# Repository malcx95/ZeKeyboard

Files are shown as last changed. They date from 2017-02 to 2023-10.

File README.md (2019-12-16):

# ZeKeyboard

ZeKeyboard is a series of home-made RGB-backlit mechanical keyboards, 
with 3D-printed bodies and custom firmware. 3 keyboards have been made,
one with 60% layout, one with a full size layout, and most recently one
with a 60% layout plus a numpad (the "V2" keyboard). This repository contains all the source
code for the firmware, as well as the 3D-models of the keyboards.

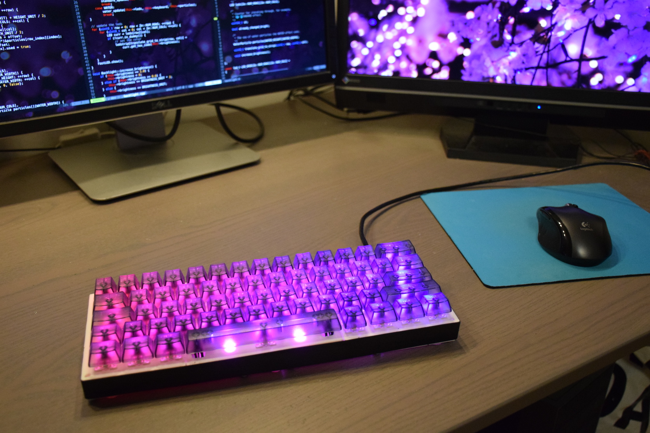
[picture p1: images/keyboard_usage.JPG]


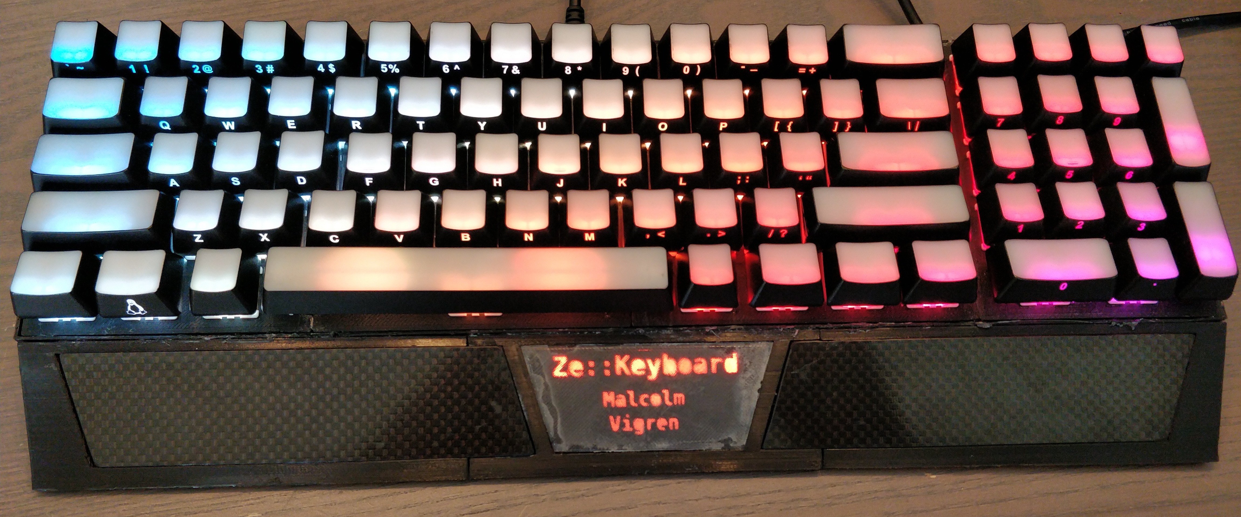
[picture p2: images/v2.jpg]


## Layout and body

The first keyboard was the one with the 60% layout, pictured below. It uses the ANSI-style Enter-key,
as well as the ISO-style left-shift key.

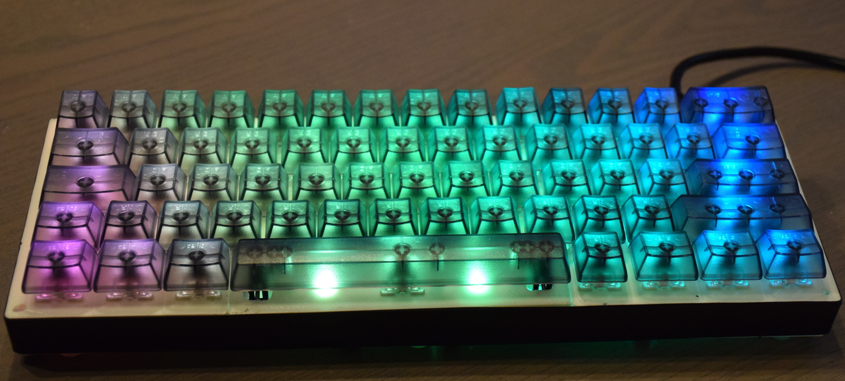
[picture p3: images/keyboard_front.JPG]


The layout for this keyboard was partially generated using scripts and 
template OpenSCAD-files by [TheZoq2](https://github.com/TheZoq2/), which
you can find [here](https://github.com/TheZoq2/Keyboard). These OpenSCAD-files
contained the switch holes corresponding to the json-layout generated from 
[here](http://www.keyboard-layout-editor.com/), and were modeled further
in Blender to form a keyboard body.

The layout for the fullsize keyboard (picture unavailable) and the V2 keyboard (pictured below)
could not be generated using the aforementioned script, so they were manually modeled
in Blender from the json-layout generated from [here](http://www.keyboard-layout-editor.com/).
The V2 body also features carbon fibre handrests.

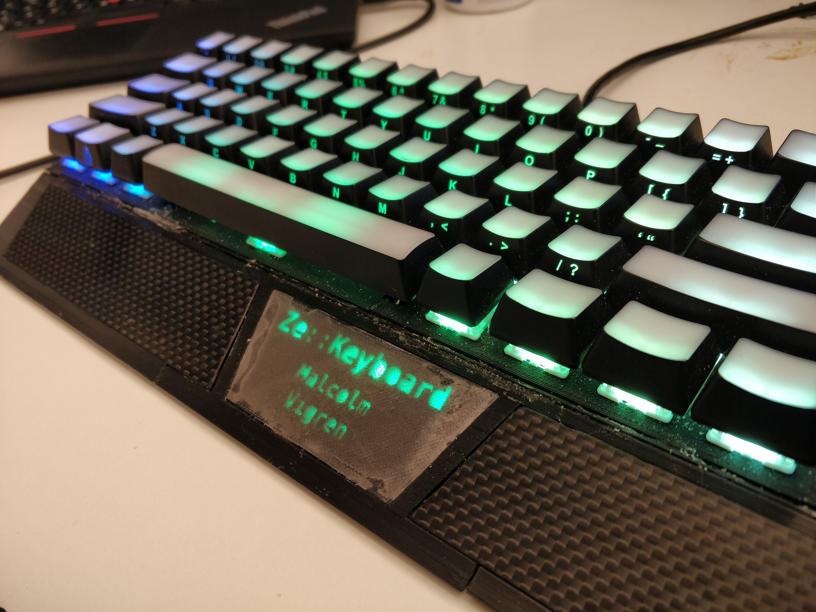
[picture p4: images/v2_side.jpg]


## Switches

All keyboards use Gateron Brown mechanical switches, which are very similar to 
Cherry MX Brown, in the sense that they have tactile feedback without a click. These
particular switches are the SMD-LED-compatible ones, meaning they have a white body
with clear top, and a large hole for an SMD-LED to shine through.

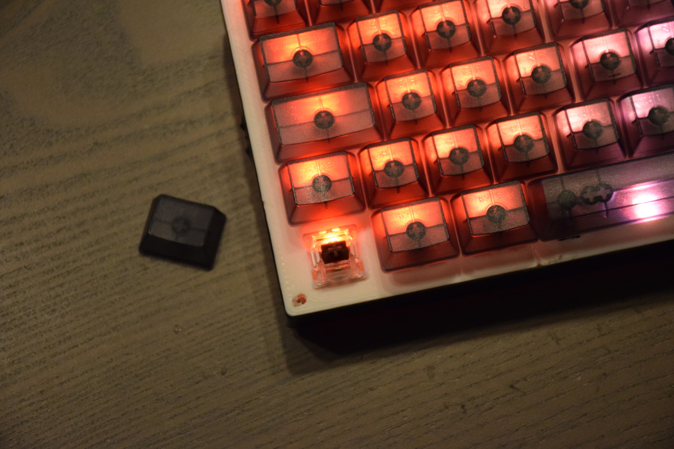
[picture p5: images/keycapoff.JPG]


## Backlight

The backlight consists of Adafruit Neopixel RGB-LEDs. Each LED is hot-glued in place
right below each switch to shine through the 
hole in the switch, lighting up the keycap. This lights
each keycap up more uniformly than LED:s mounted right below the keycap.
On the 60% and V2 keyboard are also two extra LED:s for the spacebar, to the left and right of the main LED.

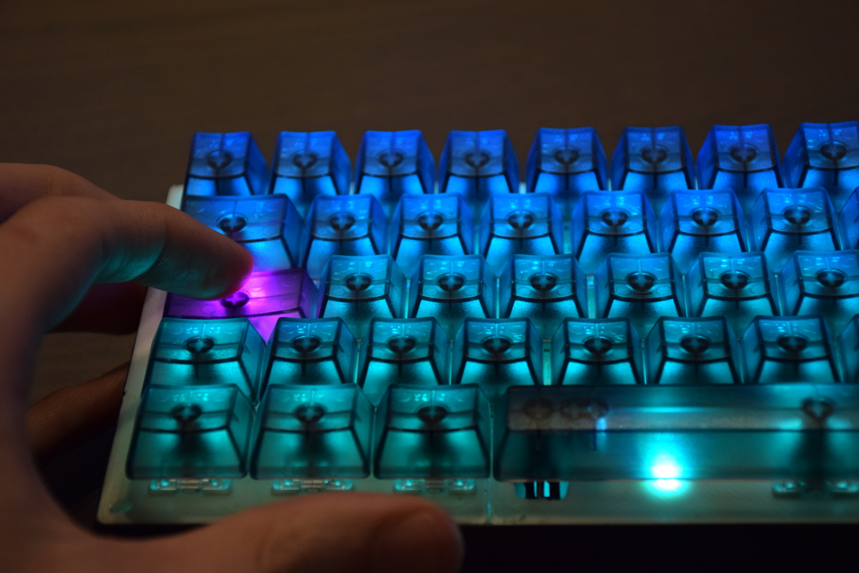
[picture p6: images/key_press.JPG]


On the V2 keyboard, there are three LED:s shining inside a cavity in the handrest, illuminating
the ZeKeyboard logo.



## Controller

For the 60% keyboard, the controller used is a Teensy 3.2. I could have chosen a cheaper Teensy, like
Teensy LC, but I wanted enough computing power for the effects I was going to implement.
Also, at the time of purchase, I had a different approach to implementing the 
backlight (involving five TLC5940 chips), which required the extra ports available on the
more expensive Teensy 3.2.

For the other keyboards, due to the larger number of keys, a Teensy 3.5 is used, as it's faster
and has more RAM.

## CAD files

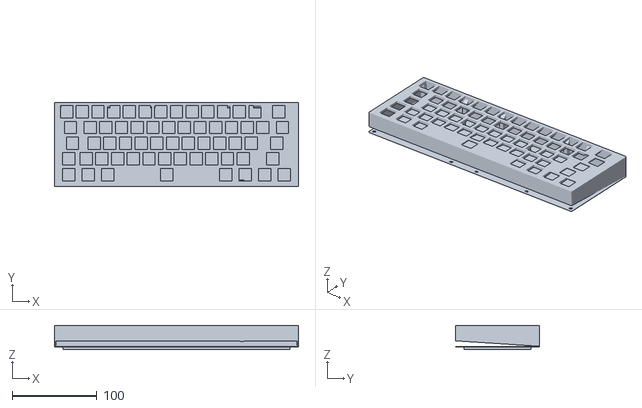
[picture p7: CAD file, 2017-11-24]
design/keyboard.stl
287.5 x 99.5 x 28.7

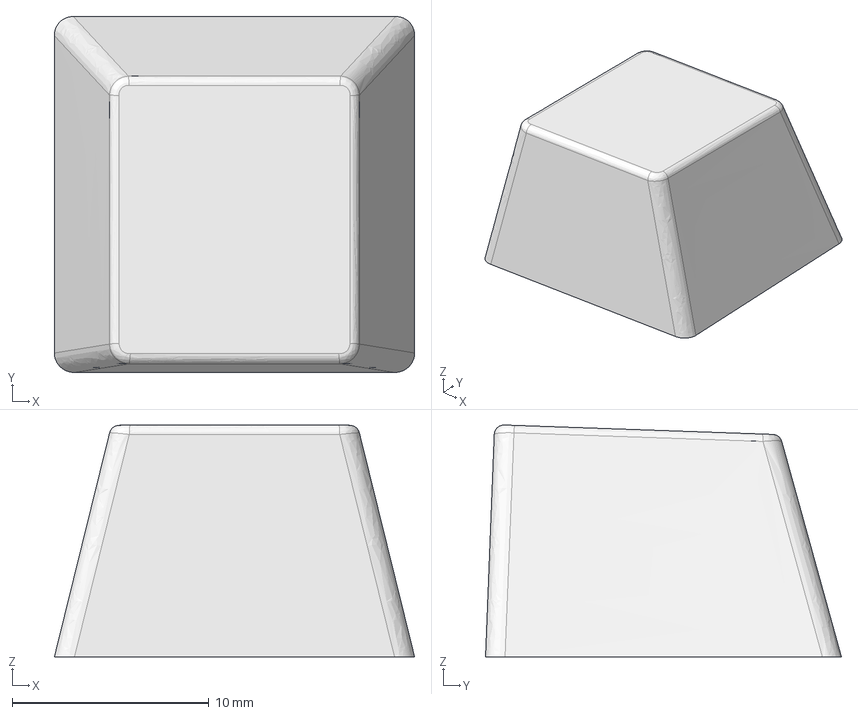
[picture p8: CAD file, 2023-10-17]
v3/case/keycap.FCStd
18.3 x 18.1 x 11.8 mm

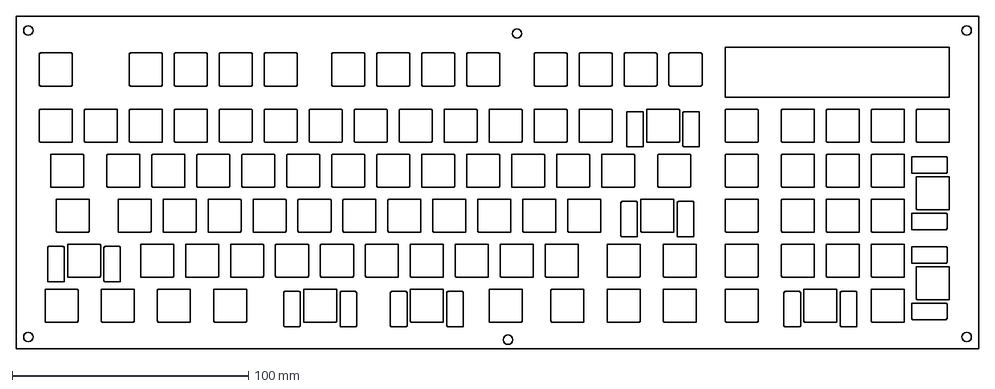
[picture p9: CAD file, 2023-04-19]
v3/pcb/production/plate/inner_plate.dxf
407.7 x 140.9 mm

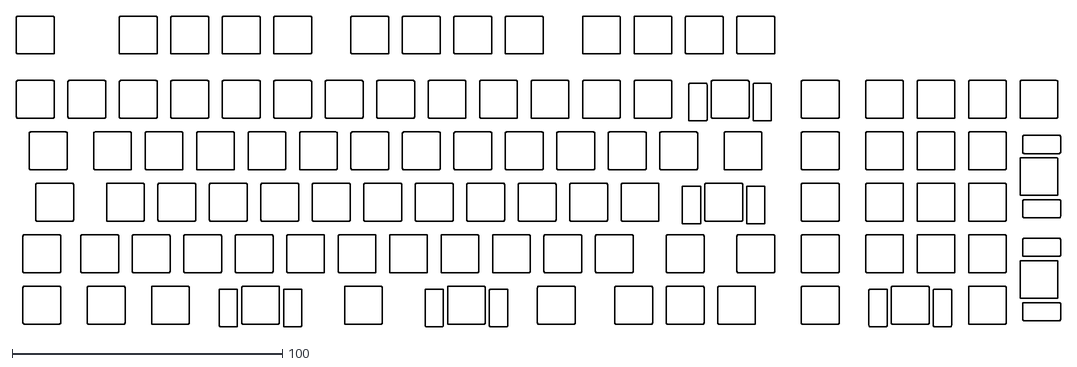
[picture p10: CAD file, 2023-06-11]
v3/case/v3-User_Eco2.dxf
386.5 x 115.0

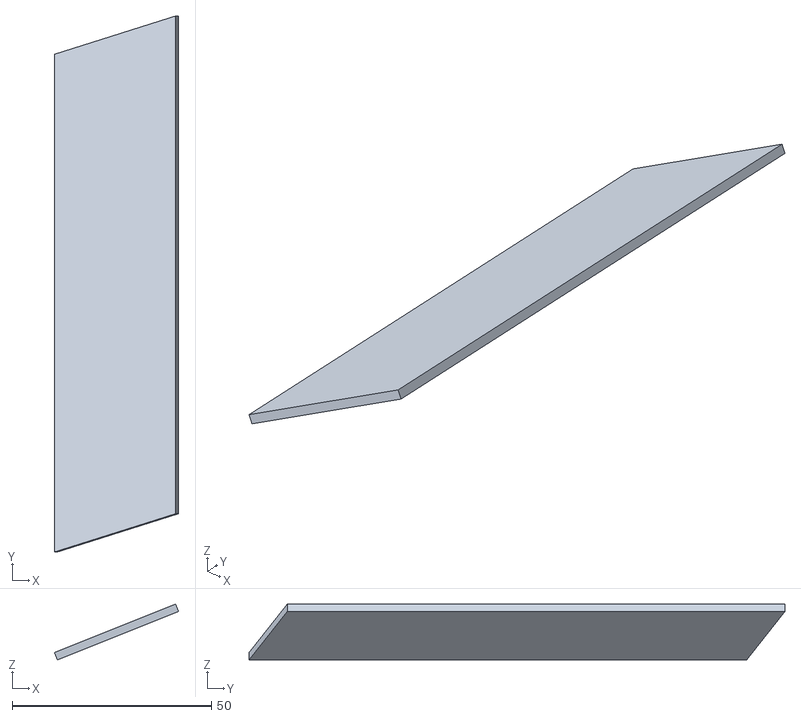
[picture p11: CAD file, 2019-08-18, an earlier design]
v2/cffull.stl
31.2 x 134.6 x 14.0

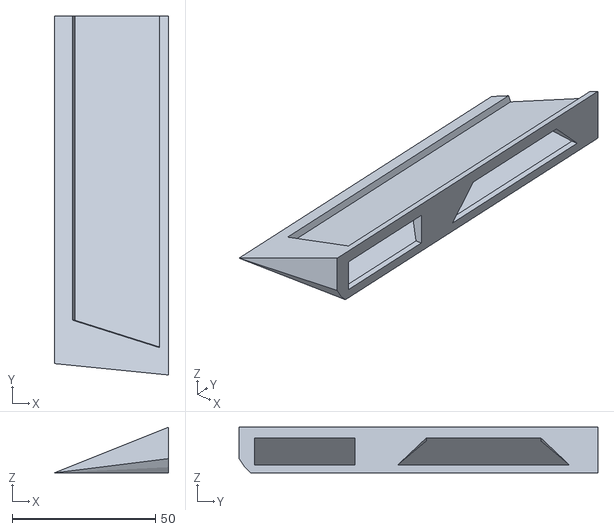
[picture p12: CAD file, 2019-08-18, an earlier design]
v2/handrest_right_full.stl
40.0 x 125.5 x 16.0

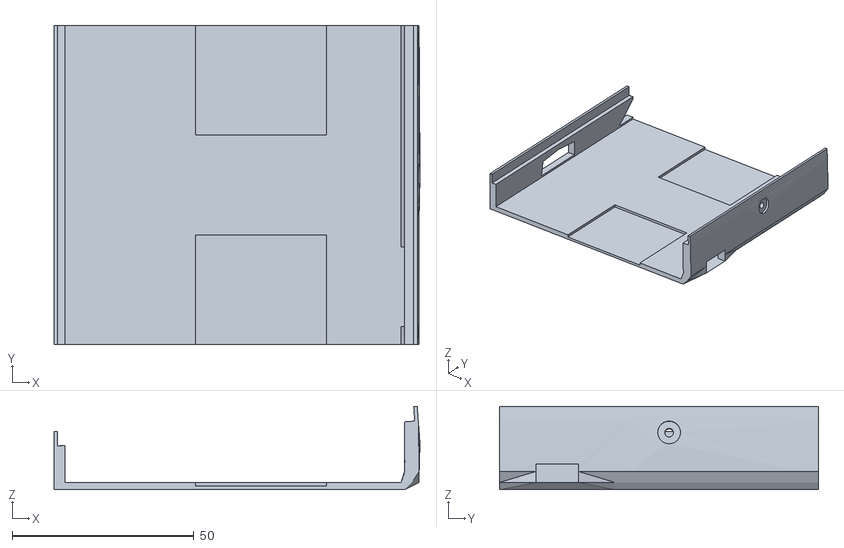
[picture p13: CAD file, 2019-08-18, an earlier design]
v2/case_center_left.stl
100.6 x 87.6 x 22.9

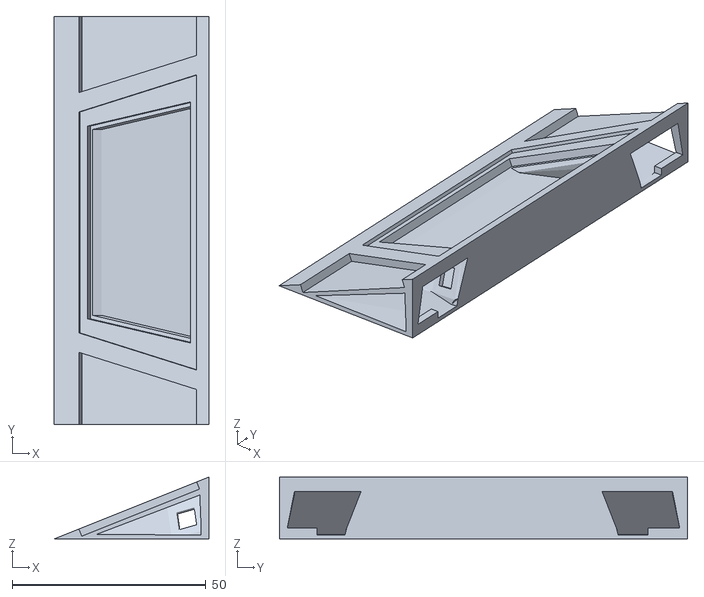
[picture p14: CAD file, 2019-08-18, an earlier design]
v2/handrest_center.stl
40.0 x 105.4 x 16.0

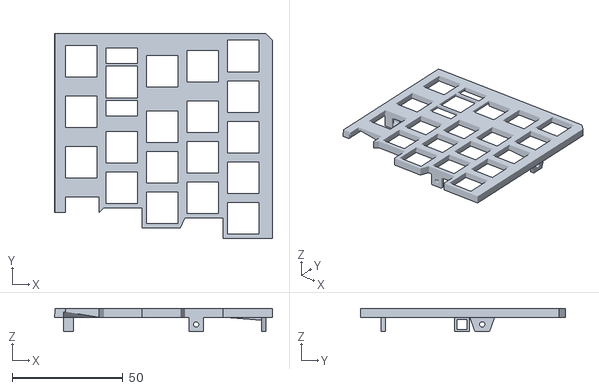
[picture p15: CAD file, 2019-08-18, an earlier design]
v2/plate_left.stl
98.5 x 92.5 x 10.4

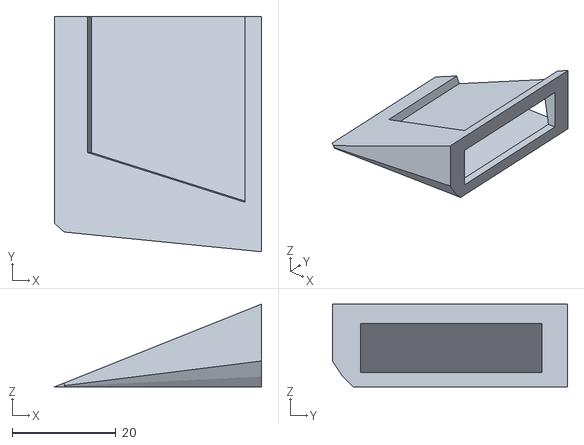
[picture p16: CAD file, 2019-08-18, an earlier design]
v2/handrest_right_edge.stl
40.0 x 45.5 x 16.0

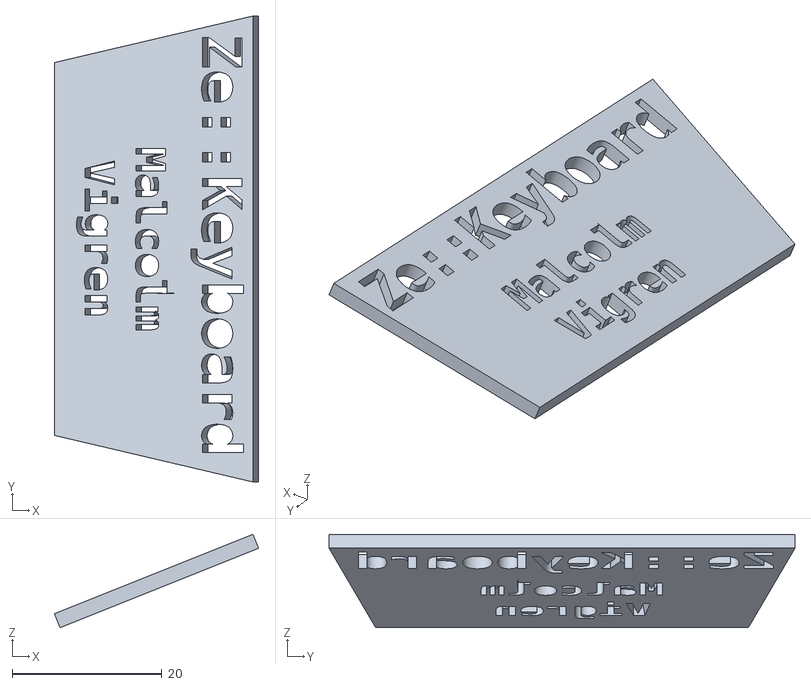
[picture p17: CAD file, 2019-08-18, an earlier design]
v2/name_tag.stl
27.3 x 62.3 x 12.5

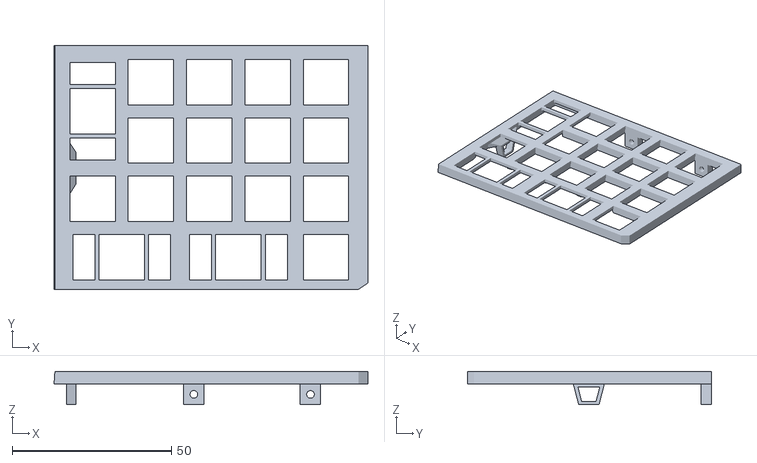
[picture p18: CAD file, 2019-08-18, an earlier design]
v2/numpad.stl
98.5 x 76.5 x 10.4

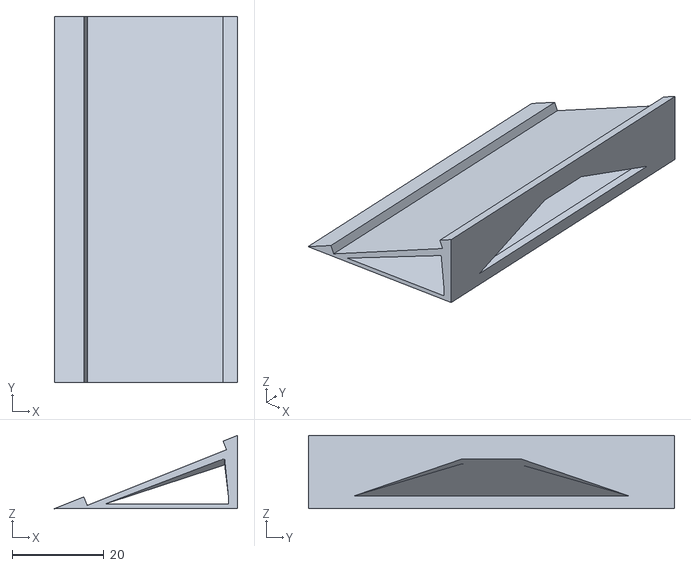
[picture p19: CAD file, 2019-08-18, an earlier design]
v2/handrest_right.stl
40.0 x 80.0 x 16.0

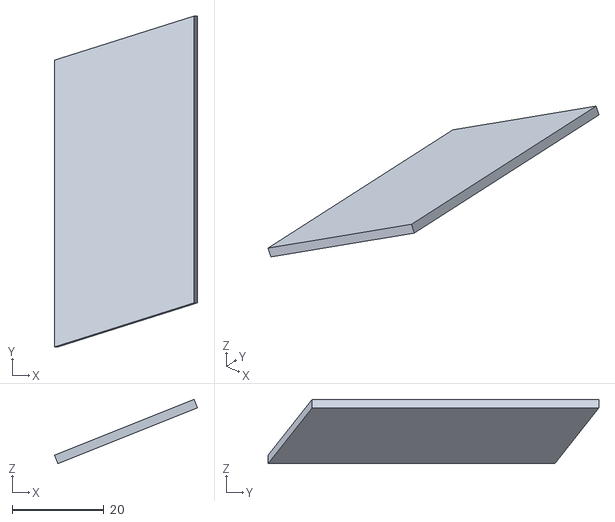
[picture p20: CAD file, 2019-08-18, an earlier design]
v2/cf1.stl
31.2 x 72.1 x 14.0

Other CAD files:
v3/pcb/production/plate/outer_plate.FCStd
v3/case/case.FCStd
v3/pcb/production/plate/even_better_inner_plate.FCStd
v2/handrest_left_full.stl
design/keyboard.blend
fullsize/fullsize.blend
v2/case_center_right.stl
v2/case_left.stl
v2/case_right.stl
v2/cf2.stl
v2/handrest_left.stl
v2/handrest_left_edge.stl
v2/joining_plate.stl
v2/nameplate.stl
v2/nameplatecover.stl
v2/nametag_cover.stl
v2/plate_center_left.stl
v2/plate_center_right.stl
v2/plate_right.stl
v2/v2.blend
v3/v3.blend

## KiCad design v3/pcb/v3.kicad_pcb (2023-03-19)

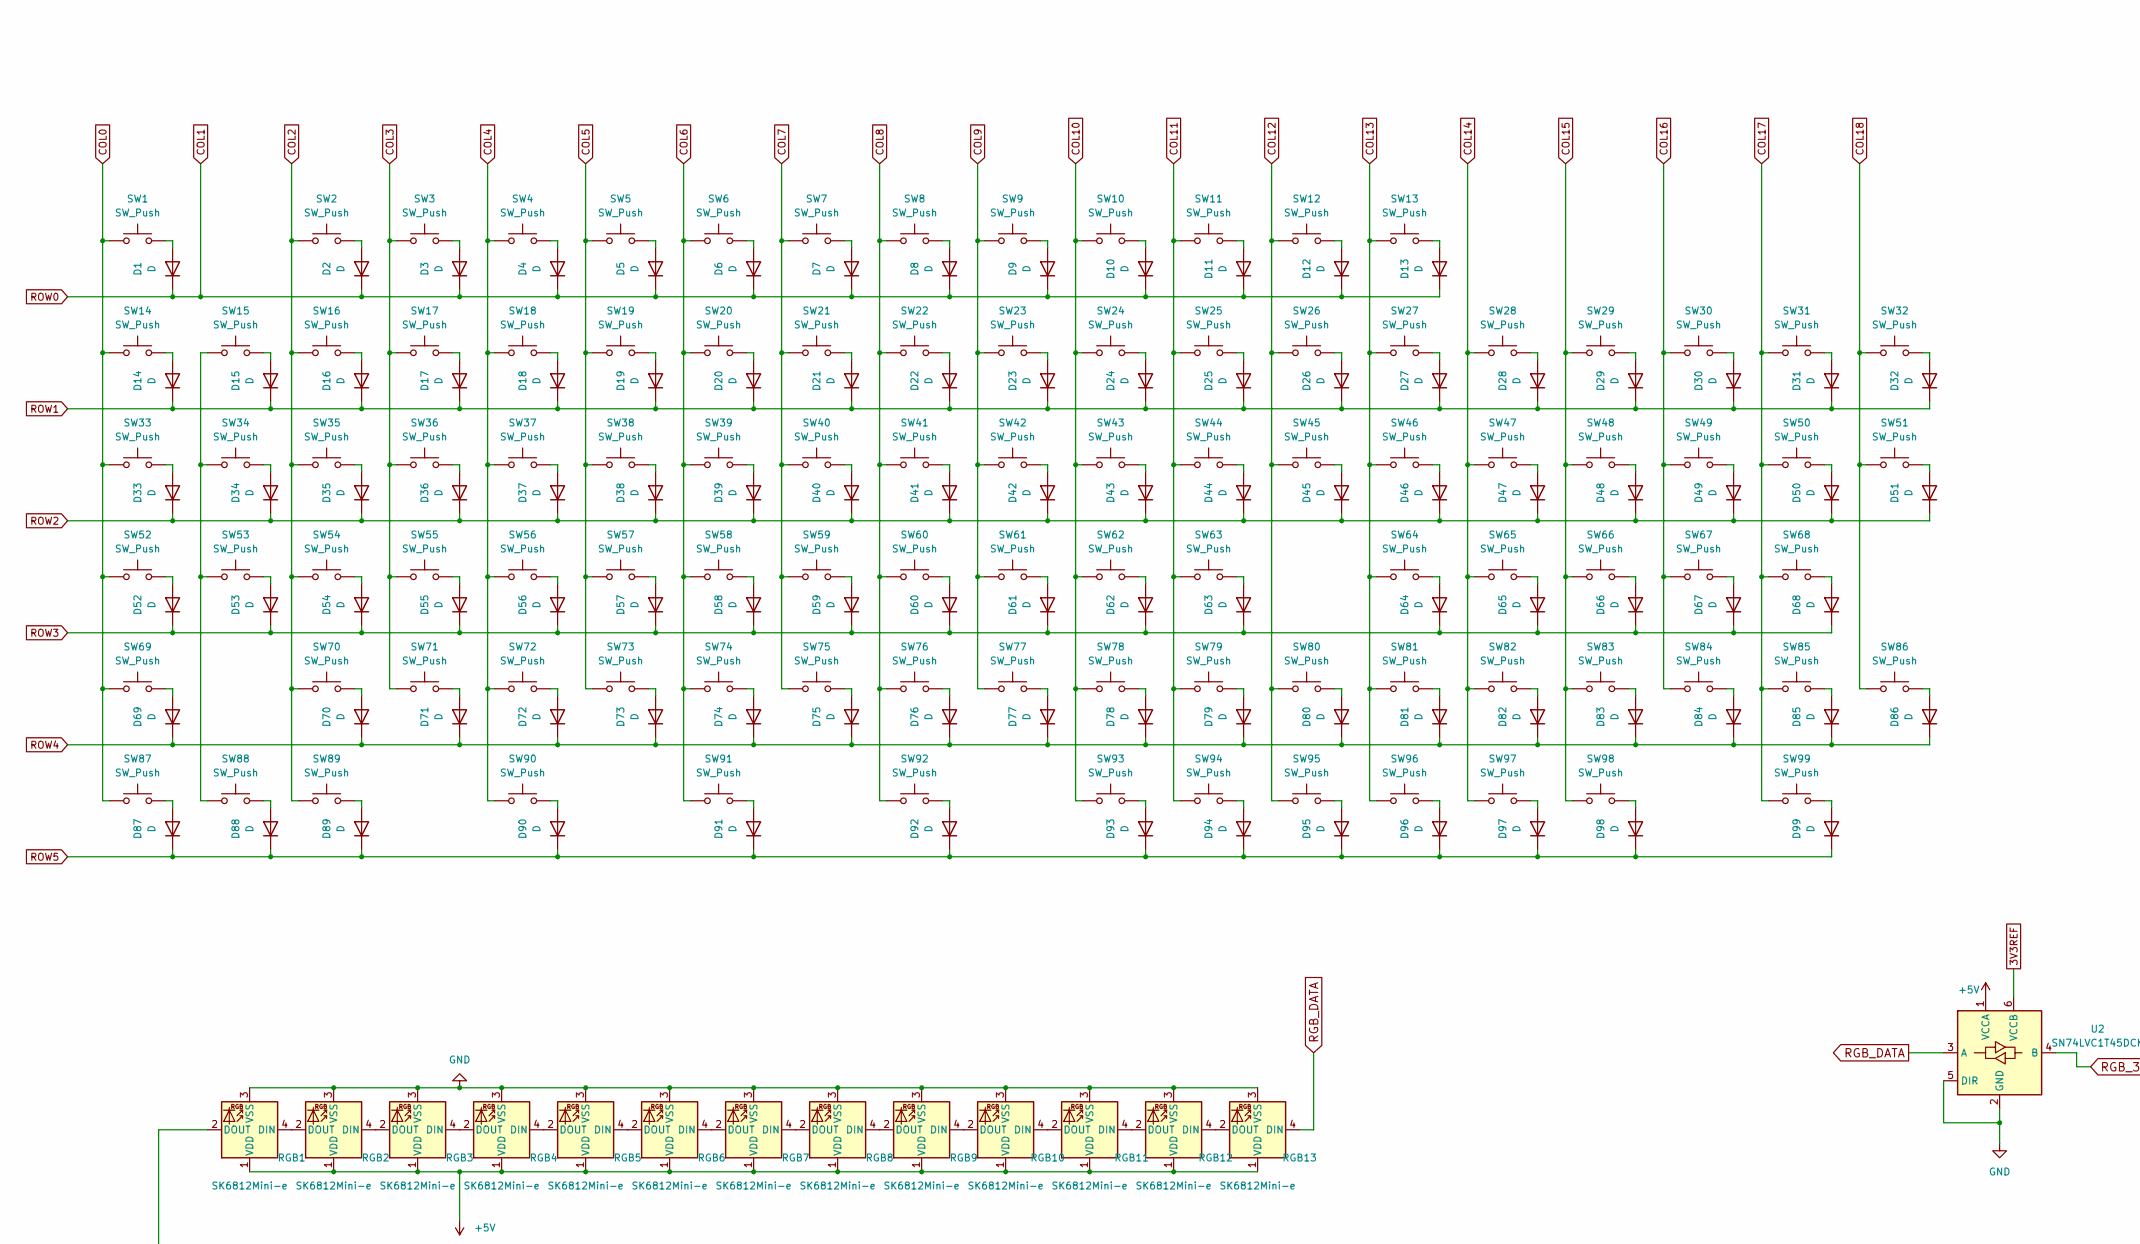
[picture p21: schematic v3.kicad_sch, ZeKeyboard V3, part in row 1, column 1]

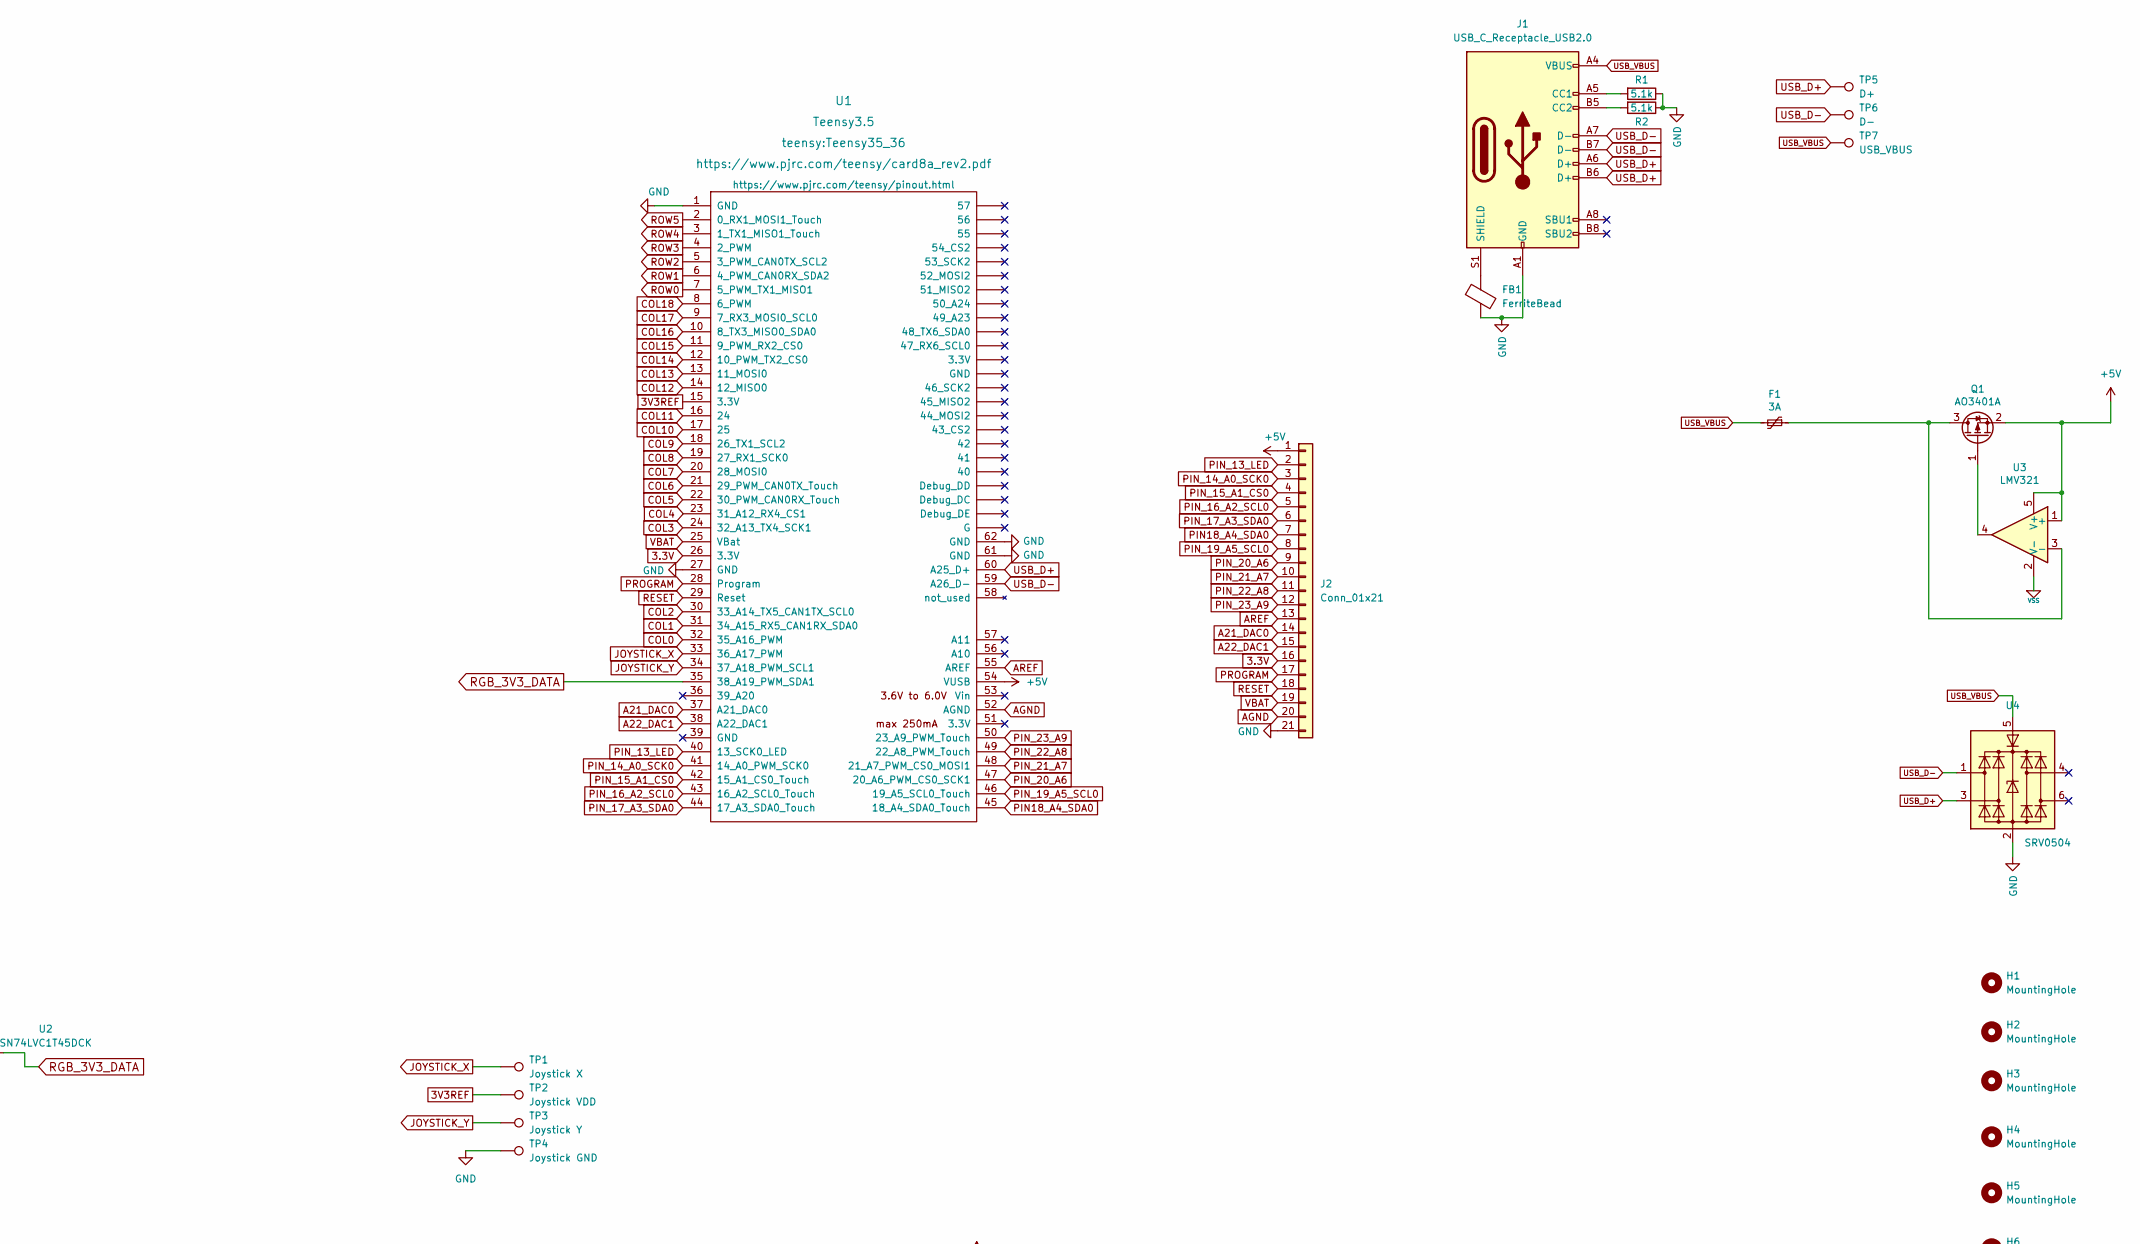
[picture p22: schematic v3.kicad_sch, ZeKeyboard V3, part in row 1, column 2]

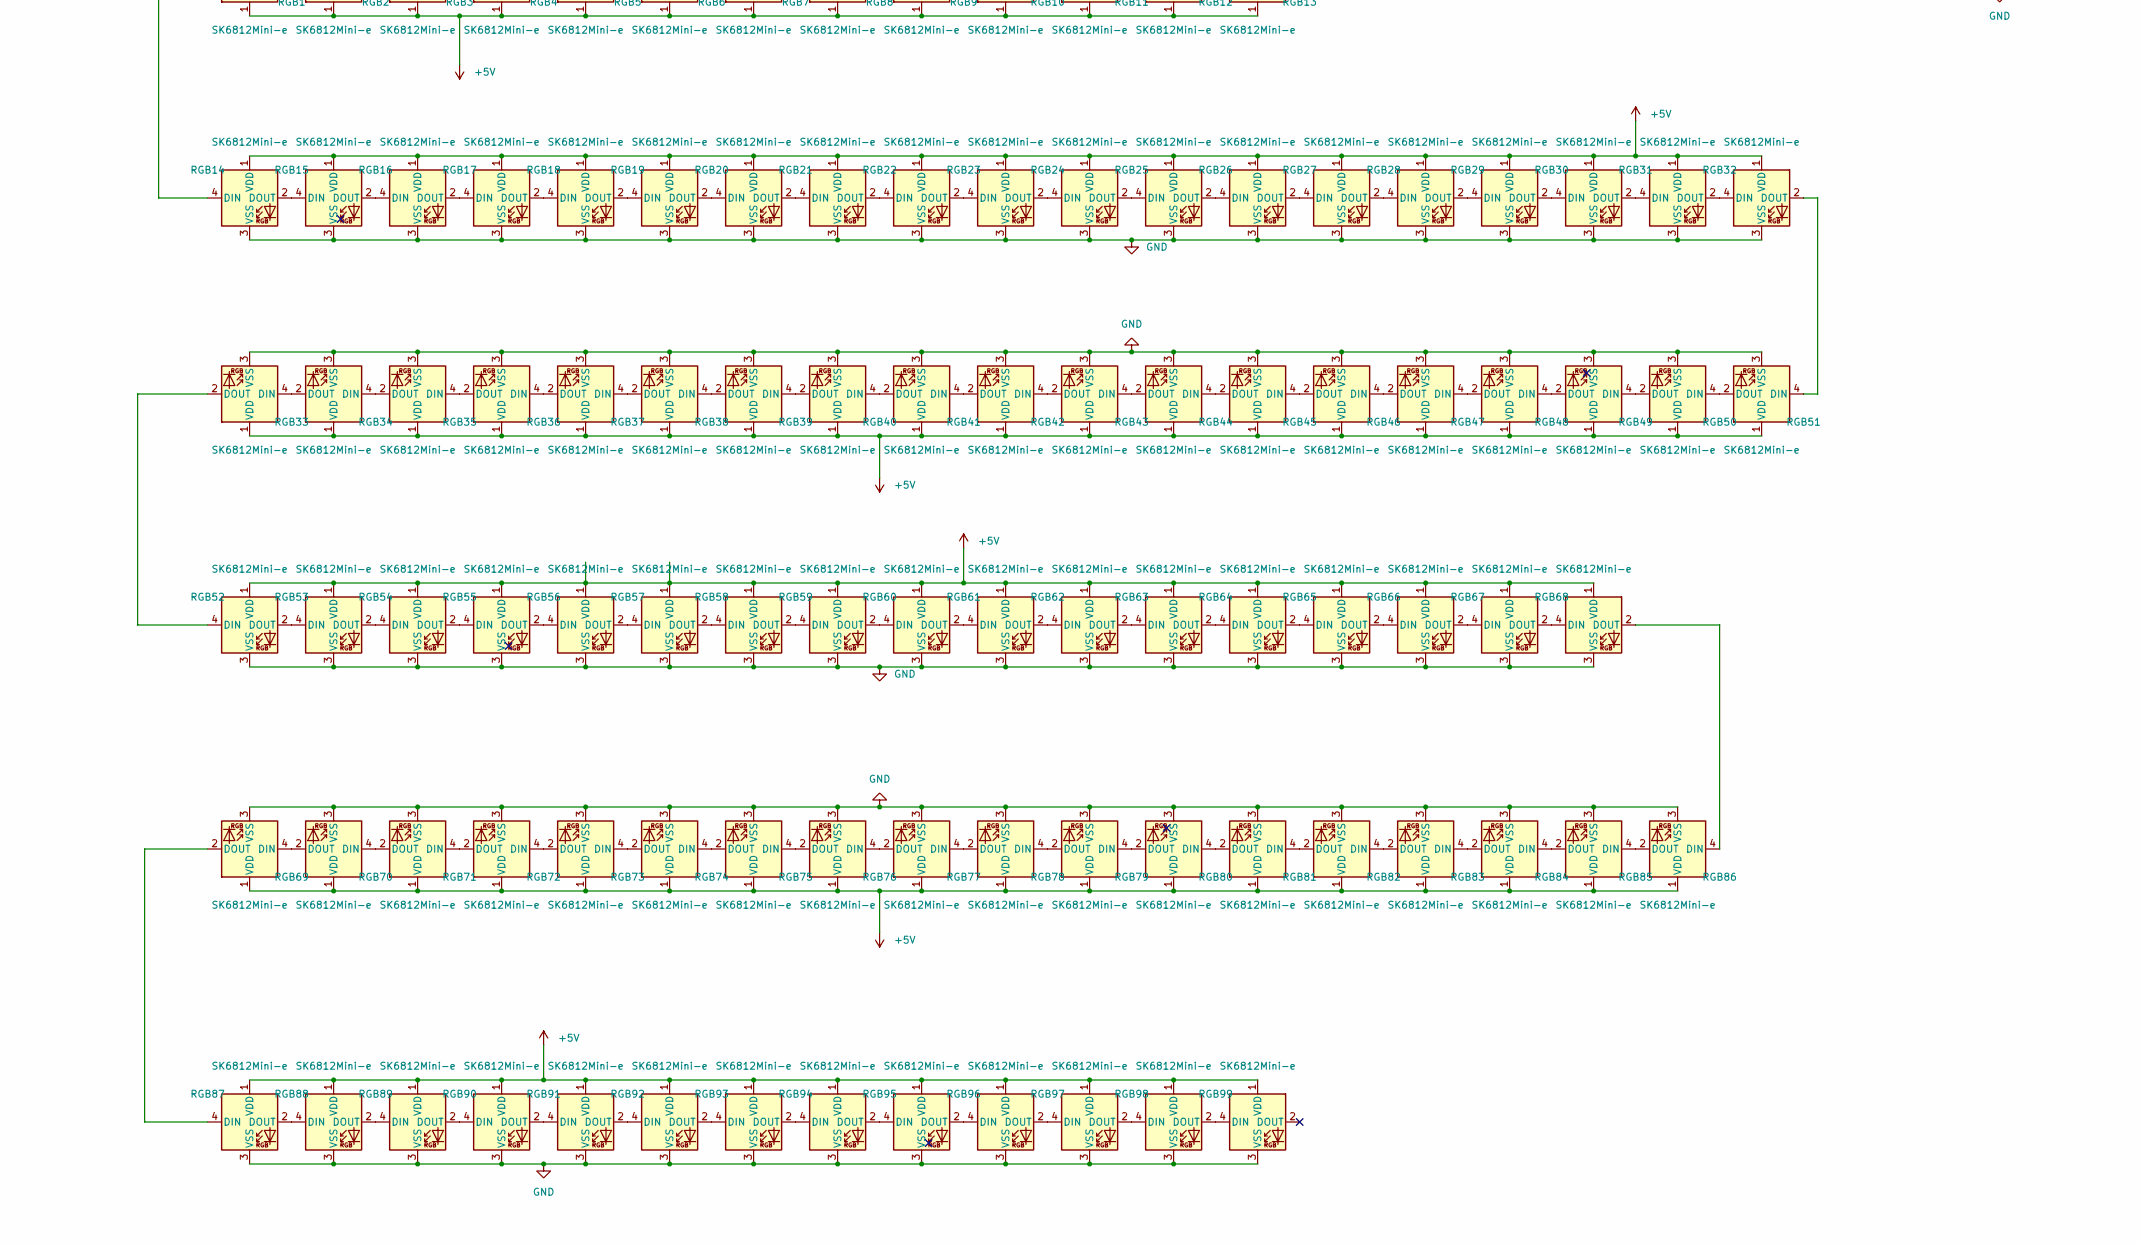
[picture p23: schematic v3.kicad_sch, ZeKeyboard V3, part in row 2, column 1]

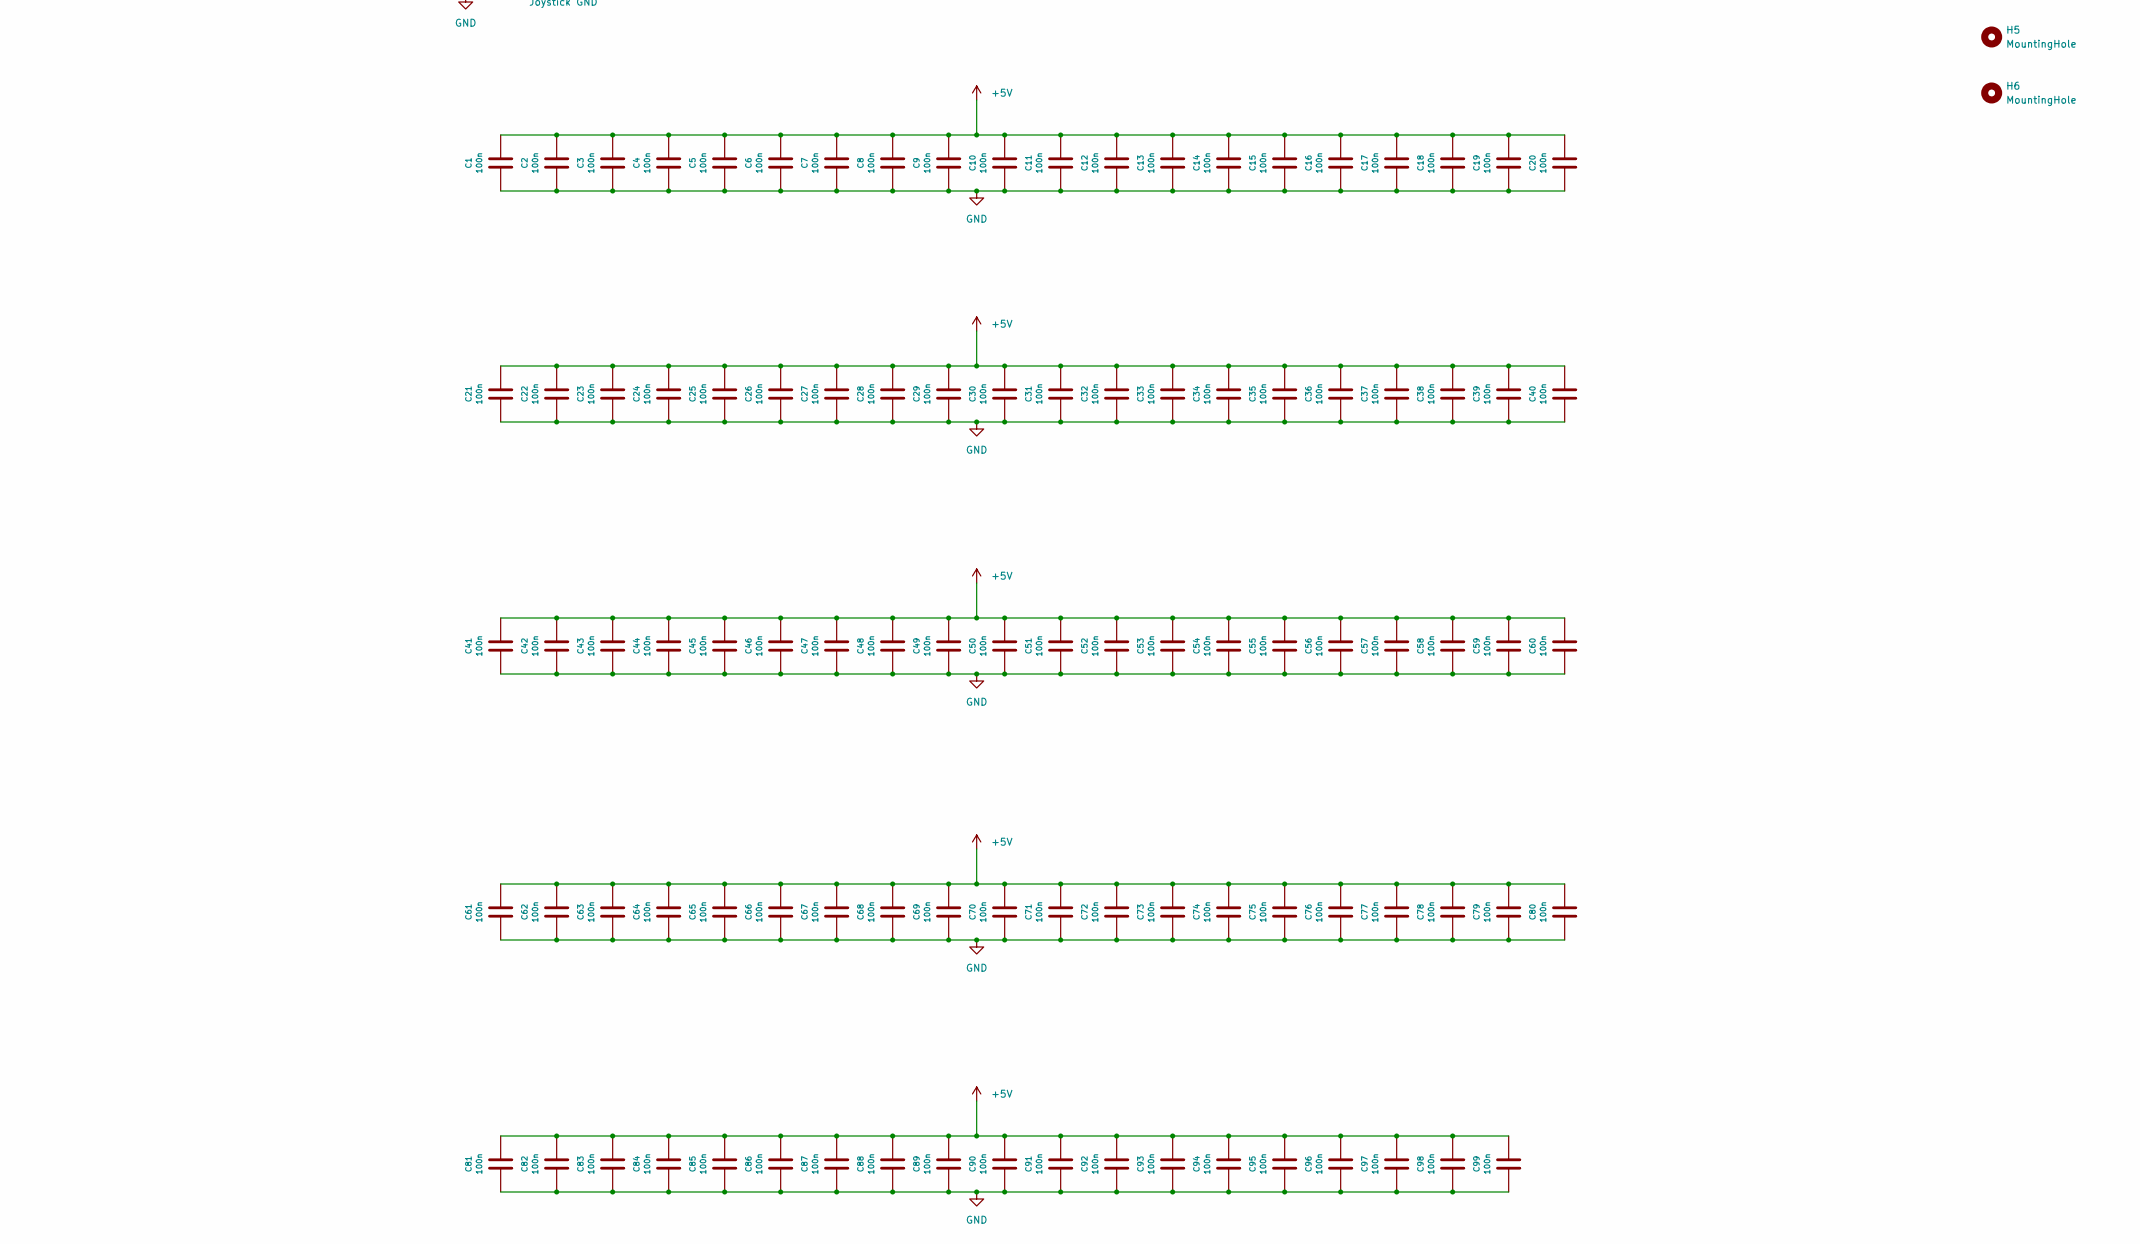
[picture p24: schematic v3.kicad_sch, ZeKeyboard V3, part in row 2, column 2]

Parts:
C1, C2, C3, C4, C5, C6, C7, C8, C9, C10, C11, C12, C13, C14, C15, C16, C17, C18, C19, C20, C21, C22, C23, C24, C25, C26, C27, C28, C29, C30, C31, C32, C33, C34, C35, C36, C37, C38, C39, C40, C41, C42, C43, C44, C45, C46, C47, C48, C49, C50, C51, C52, C53, C54, C55, C56, C57, C58, C59, C60, C61, C62, C63, C64, C65, C66, C67, C68, C69, C70, C71, C72, C73, C74, C75, C76, C77, C78, C79, C80, C81, C82, C83, C84, C85, C86, C87, C88, C89, C90, C91, C92, C93, C94, C95, C96, C97, C98, C99: 100n; SMD-0603; LCSC Part C14663
D1, D2, D3, D4, D5, D6, D7, D8, D9, D10, D11, D12, D13, D14, D15, D16, D17, D18, D19, D20, D21, D22, D23, D24, D25, D26, D27, D28, D29, D30, D31, D32, D33, D34, D35, D36, D37, D38, D39, D40, D41, D42, D43, D44, D45, D46, D47, D48, D49, D50, D51, D52, D53, D54, D55, D56, D57, D58, D59, D60, D61, D62, D63, D64, D65, D66, D67, D68, D69, D70, D71, D72, D73, D74, D75, D76, D77, D78, D79, D80, D81, D82, D83, D84, D85, D86, D87, D88, D89, D90, D91, D92, D93, D94, D95, D96, D97, D98, D99: D; D_SOD-323F
F1: 3A; Fuse_1206_3216Metric; LCSC Part C70085
FB1: FerriteBead; R_0402_1005Metric; LCSC C668229
H1, H2, H3, H4, H5, H6: MountingHole; MountingHole_3.5mm
J1: USB_C_Receptacle_USB2.0; USB_C_Receptacle_HRO_TYPE-C-31-M-12
J2: Conn_01x21; PinHeader_1x21_P2.00mm_Vertical
Q1: AO3401A; SOT-23; LCSC Part C15127
R1, R2: 5.1k; R_0603_1608Metric; Mouser C27834
RGB1, RGB2, RGB3, RGB4, RGB5, RGB6, RGB7, RGB8, RGB9, RGB10, RGB11, RGB12, RGB13, RGB14, RGB15, RGB16, RGB17, RGB18, RGB19, RGB20, RGB21, RGB22, RGB23, RGB24, RGB25, RGB26, RGB27, RGB28, RGB29, RGB30, RGB31, RGB32, RGB33, RGB34, RGB35, RGB36, RGB37, RGB38, RGB39, RGB40, RGB41, RGB42, RGB43, RGB44, RGB45, RGB46, RGB47, RGB48, RGB49, RGB50, RGB51, RGB52, RGB53, RGB54, RGB55, RGB56, RGB57, RGB58, RGB59, RGB60, RGB61, RGB62, RGB63, RGB64, RGB65, RGB66, RGB67, RGB68, RGB69, RGB70, RGB71, RGB72, RGB73, RGB74, RGB75, RGB76, RGB77, RGB78, RGB79, RGB80, RGB81, RGB82, RGB83, RGB84, RGB85, RGB86, RGB87, RGB88, RGB89, RGB90, RGB91, RGB92, RGB93, RGB94, RGB95, RGB96, RGB97, RGB98, RGB99: SK6812Mini-e; SK6812_mini_e_flipable; JLCPCB BOM 0
SW1, SW2, SW3, SW4, SW5, SW6, SW7, SW8, SW9, SW10, SW11, SW12, SW13, SW14, SW15, SW16, SW17, SW18, SW19, SW20, SW21, SW22, SW23, SW24, SW25, SW26, SW28, SW29, SW30, SW31, SW32, SW33, SW34, SW35, SW36, SW37, SW38, SW39, SW40, SW41, SW42, SW43, SW44, SW45, SW46, SW47, SW48, SW49, SW50, SW52, SW53, SW54, SW55, SW56, SW57, SW58, SW59, SW60, SW61, SW62, SW63, SW65, SW66, SW67, SW68, SW69, SW70, SW71, SW72, SW73, SW74, SW75, SW76, SW77, SW78, SW79, SW80, SW81, SW82, SW83, SW84, SW85, SW87, SW88, SW89, SW90, SW93, SW94, SW95, SW96, SW97, SW99: SW_Push; MX_KAILH_SOCKET_1U
SW27, SW64, SW91, SW92, SW98: SW_Push; MX_KAILH_SOCKET_2U_STAB
SW51, SW86: SW_Push; MX_KAILH_SOCKET_2U_STAB_VERT
TP1: Joystick X; TestPoint_THTPad_D1.5mm_Drill0.7mm
TP2: Joystick VDD; TestPoint_THTPad_D1.5mm_Drill0.7mm
TP3: Joystick Y; TestPoint_THTPad_D1.5mm_Drill0.7mm
TP4: Joystick GND; TestPoint_THTPad_D1.5mm_Drill0.7mm
TP5: D+; TestPoint_THTPad_D1.5mm_Drill0.7mm
TP6: D-; TestPoint_THTPad_D1.5mm_Drill0.7mm
TP7: USB_VBUS; TestPoint_THTPad_D1.5mm_Drill0.7mm
U1: Teensy3.5; Teensy35_36
U2: SN74LVC1T45DCK; SOT-363_SC-70-6
U3: LMV321; SOT-23-5; JLCPCB BOM 1
U4: SRV0504; SOT-23-6; JLCPCB BOM 1

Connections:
3.3V: J2.16, U1.26 (3.3V)
3V3REF: TP2.1, U1.15 (3.3V), U2.6 (VCCB)
+5V: C1.1, C2.1, C3.1, C4.1, C5.1, C6.1, C7.1, C8.1, C9.1, C10.1, C11.1, C12.1, C13.1, C14.1, C15.1, C16.1, C17.1, C18.1, C19.1, C20.1, C21.1, C22.1, C23.1, C24.1, C25.1, C26.1, C27.1, C28.1, C29.1, C30.1, C31.1, C32.1, C33.1, C34.1, C35.1, C36.1, C37.1, C38.1, C39.1, C40.1, C41.1, C42.1, C43.1, C44.1, C45.1, C46.1, C47.1, C48.1, C49.1, C50.1, C51.1, C52.1, C53.1, C54.1, C55.1, C56.1, C57.1, C58.1, C59.1, C60.1, C61.1, C62.1, C63.1, C64.1, C65.1, C66.1, C67.1, C68.1, C69.1, C70.1, C71.1, C72.1, C73.1, C74.1, C75.1, C76.1, C77.1, C78.1, C79.1, C80.1, C81.1, C82.1, C83.1, C84.1, C85.1, C86.1, C87.1, C88.1, C89.1, C90.1, C91.1, C92.1, C93.1, C94.1, C95.1, C96.1, C97.1, C98.1, C99.1, J2.1, Q1.2 (S), RGB1.1 (VDD), RGB2.1 (VDD), RGB3.1 (VDD), RGB4.1 (VDD), RGB5.1 (VDD), RGB6.1 (VDD), RGB7.1 (VDD), RGB8.1 (VDD), RGB9.1 (VDD), RGB10.1 (VDD), RGB11.1 (VDD), RGB12.1 (VDD), RGB13.1 (VDD), RGB14.1 (VDD), RGB15.1 (VDD), RGB16.1 (VDD), RGB17.1 (VDD), RGB18.1 (VDD), RGB19.1 (VDD), RGB20.1 (VDD), RGB21.1 (VDD), RGB22.1 (VDD), RGB23.1 (VDD), RGB24.1 (VDD), RGB25.1 (VDD), RGB26.1 (VDD), RGB27.1 (VDD), RGB28.1 (VDD), RGB29.1 (VDD), RGB30.1 (VDD), RGB31.1 (VDD), RGB32.1 (VDD), RGB33.1 (VDD), RGB34.1 (VDD), RGB35.1 (VDD), RGB36.1 (VDD), RGB37.1 (VDD), RGB38.1 (VDD), RGB39.1 (VDD), RGB40.1 (VDD), RGB41.1 (VDD), RGB42.1 (VDD), RGB43.1 (VDD), RGB44.1 (VDD), RGB45.1 (VDD), RGB46.1 (VDD), RGB47.1 (VDD), RGB48.1 (VDD), RGB49.1 (VDD), RGB50.1 (VDD), RGB51.1 (VDD), RGB52.1 (VDD), RGB53.1 (VDD), RGB54.1 (VDD), RGB55.1 (VDD), RGB56.1 (VDD), RGB57.1 (VDD), RGB58.1 (VDD), RGB59.1 (VDD), RGB60.1 (VDD), RGB61.1 (VDD), RGB62.1 (VDD), RGB63.1 (VDD), RGB64.1 (VDD), RGB65.1 (VDD), RGB66.1 (VDD), RGB67.1 (VDD), RGB68.1 (VDD), RGB69.1 (VDD), RGB70.1 (VDD), RGB71.1 (VDD), RGB72.1 (VDD), RGB73.1 (VDD), RGB74.1 (VDD), RGB75.1 (VDD), RGB76.1 (VDD), RGB77.1 (VDD), RGB78.1 (VDD), RGB79.1 (VDD), RGB80.1 (VDD), RGB81.1 (VDD), RGB82.1 (VDD), RGB83.1 (VDD), RGB84.1 (VDD), RGB85.1 (VDD), RGB86.1 (VDD), RGB87.1 (VDD), RGB88.1 (VDD), RGB89.1 (VDD), RGB90.1 (VDD), RGB91.1 (VDD), RGB92.1 (VDD), RGB93.1 (VDD), RGB94.1 (VDD), RGB95.1 (VDD), RGB96.1 (VDD), RGB97.1 (VDD), RGB98.1 (VDD), RGB99.1 (VDD), U1.54 (VUSB), U2.1 (VCCA), U3.1 (+), U3.5 (V+)
A21_DAC0: J2.14, U1.37 (A21_DAC0)
A22_DAC1: J2.15, U1.38 (A22_DAC1)
AGND: J2.20, U1.52 (AGND)
AREF: J2.13, U1.55 (AREF)
COL0: SW1.1, SW14.1, SW33.1, SW52.1, SW69.1, SW87.1, U1.32 (35_A16_PWM)
COL1: D1.1 (K), D2.1 (K), D3.1 (K), D4.1 (K), D5.1 (K), D6.1 (K), D7.1 (K), D8.1 (K), D9.1 (K), D10.1 (K), D11.1 (K), D12.1 (K), D13.1 (K), U1.7 (5_PWM_TX1_MISO1), U1.31 (34_A15_RX5_CAN1RX_SDA0)
COL2: SW2.1, SW16.1, SW35.1, SW54.1, SW70.1, SW89.1, U1.30 (33_A14_TX5_CAN1TX_SCL0)
COL3: SW3.1, SW17.1, SW36.1, SW55.1, SW71.1, U1.24 (32_A13_TX4_SCK1)
COL4: SW4.1, SW18.1, SW37.1, SW56.1, SW72.1, SW90.1, U1.23 (31_A12_RX4_CS1)
COL5: SW5.1, SW19.1, SW38.1, SW57.1, SW73.1, U1.22 (30_PWM_CAN0RX_Touch)
COL6: SW6.1, SW20.1, SW39.1, SW58.1, SW74.1, SW91.1, U1.21 (29_PWM_CAN0TX_Touch)
COL7: SW7.1, SW21.1, SW40.1, SW59.1, SW75.1, U1.20 (28_MOSI0)
COL8: SW8.1, SW22.1, SW41.1, SW60.1, SW76.1, SW92.1, U1.19 (27_RX1_SCK0)
COL9: SW9.1, SW23.1, SW42.1, SW61.1, SW77.1, U1.18 (26_TX1_SCL2)
COL10: SW10.1, SW24.1, SW43.1, SW62.1, SW78.1, SW93.1, U1.17 (25)
COL11: SW11.1, SW25.1, SW44.1, SW63.1, SW79.1, SW94.1, U1.16 (24)
COL12: SW12.1, SW26.1, SW45.1, SW80.1, SW95.1, U1.14 (12_MISO0)
COL13: SW13.1, SW27.1, SW46.1, SW64.1, SW81.1, SW96.1, U1.13 (11_MOSI0)
COL14: SW28.1, SW47.1, SW65.1, SW82.1, SW97.1, U1.12 (10_PWM_TX2_CS0)
COL15: SW29.1, SW48.1, SW66.1, SW83.1, SW98.1, U1.11 (9_PWM_RX2_CS0)
COL16: SW30.1, SW49.1, SW67.1, SW84.1, U1.10 (8_TX3_MISO0_SDA0)
COL17: SW31.1, SW50.1, SW68.1, SW85.1, SW99.1, U1.9 (7_RX3_MOSI0_SCL0)
COL18: SW32.1, SW51.1, SW86.1, U1.8 (6_PWM)
GND: C1.2, C2.2, C3.2, C4.2, C5.2, C6.2, C7.2, C8.2, C9.2, C10.2, C11.2, C12.2, C13.2, C14.2, C15.2, C16.2, C17.2, C18.2, C19.2, C20.2, C21.2, C22.2, C23.2, C24.2, C25.2, C26.2, C27.2, C28.2, C29.2, C30.2, C31.2, C32.2, C33.2, C34.2, C35.2, C36.2, C37.2, C38.2, C39.2, C40.2, C41.2, C42.2, C43.2, C44.2, C45.2, C46.2, C47.2, C48.2, C49.2, C50.2, C51.2, C52.2, C53.2, C54.2, C55.2, C56.2, C57.2, C58.2, C59.2, C60.2, C61.2, C62.2, C63.2, C64.2, C65.2, C66.2, C67.2, C68.2, C69.2, C70.2, C71.2, C72.2, C73.2, C74.2, C75.2, C76.2, C77.2, C78.2, C79.2, C80.2, C81.2, C82.2, C83.2, C84.2, C85.2, C86.2, C87.2, C88.2, C89.2, C90.2, C91.2, C92.2, C93.2, C94.2, C95.2, C96.2, C97.2, C98.2, C99.2, FB1.2, J1.A1 (GND), J1.A12 (GND), J1.B1 (GND), J1.B12 (GND), J2.21, R1.1, R2.1, RGB1.3 (VSS), RGB2.3 (VSS), RGB3.3 (VSS), RGB4.3 (VSS), RGB5.3 (VSS), RGB6.3 (VSS), RGB7.3 (VSS), RGB8.3 (VSS), RGB9.3 (VSS), RGB10.3 (VSS), RGB11.3 (VSS), RGB12.3 (VSS), RGB13.3 (VSS), RGB14.3 (VSS), RGB15.3 (VSS), RGB16.3 (VSS), RGB17.3 (VSS), RGB18.3 (VSS), RGB19.3 (VSS), RGB20.3 (VSS), RGB21.3 (VSS), RGB22.3 (VSS), RGB23.3 (VSS), RGB24.3 (VSS), RGB25.3 (VSS), RGB26.3 (VSS), RGB27.3 (VSS), RGB28.3 (VSS), RGB29.3 (VSS), RGB30.3 (VSS), RGB31.3 (VSS), RGB32.3 (VSS), RGB33.3 (VSS), RGB34.3 (VSS), RGB35.3 (VSS), RGB36.3 (VSS), RGB37.3 (VSS), RGB38.3 (VSS), RGB39.3 (VSS), RGB40.3 (VSS), RGB41.3 (VSS), RGB42.3 (VSS), RGB43.3 (VSS), RGB44.3 (VSS), RGB45.3 (VSS), RGB46.3 (VSS), RGB47.3 (VSS), RGB48.3 (VSS), RGB49.3 (VSS), RGB50.3 (VSS), RGB51.3 (VSS), RGB52.3 (VSS), RGB53.3 (VSS), RGB54.3 (VSS), RGB55.3 (VSS), RGB56.3 (VSS), RGB57.3 (VSS), RGB58.3 (VSS), RGB59.3 (VSS), RGB60.3 (VSS), RGB61.3 (VSS), RGB62.3 (VSS), RGB63.3 (VSS), RGB64.3 (VSS), RGB65.3 (VSS), RGB66.3 (VSS), RGB67.3 (VSS), RGB68.3 (VSS), RGB69.3 (VSS), RGB70.3 (VSS), RGB71.3 (VSS), RGB72.3 (VSS), RGB73.3 (VSS), RGB74.3 (VSS), RGB75.3 (VSS), RGB76.3 (VSS), RGB77.3 (VSS), RGB78.3 (VSS), RGB79.3 (VSS), RGB80.3 (VSS), RGB81.3 (VSS), RGB82.3 (VSS), RGB83.3 (VSS), RGB84.3 (VSS), RGB85.3 (VSS), RGB86.3 (VSS), RGB87.3 (VSS), RGB88.3 (VSS), RGB89.3 (VSS), RGB90.3 (VSS), RGB91.3 (VSS), RGB92.3 (VSS), RGB93.3 (VSS), RGB94.3 (VSS), RGB95.3 (VSS), RGB96.3 (VSS), RGB97.3 (VSS), RGB98.3 (VSS), RGB99.3 (VSS), TP4.1, U1.1 (GND), U1.27 (GND), U1.61 (GND), U1.62 (GND), U2.2 (GND), U2.5 (DIR), U4.2 (GND)
JOYSTICK_X: TP1.1, U1.33 (36_A17_PWM)
JOYSTICK_Y: TP3.1, U1.34 (37_A18_PWM_SCL1)
unnamed: D1.2 (A), SW1.2
unnamed: D2.2 (A), SW2.2
unnamed: D3.2 (A), SW3.2
unnamed: D4.2 (A), SW4.2
unnamed: D5.2 (A), SW5.2
unnamed: D6.2 (A), SW6.2
unnamed: D7.2 (A), SW7.2
unnamed: D8.2 (A), SW8.2
unnamed: D9.2 (A), SW9.2
unnamed: D10.2 (A), SW10.2
unnamed: D11.2 (A), SW11.2
unnamed: D12.2 (A), SW12.2
unnamed: D13.2 (A), SW13.2
unnamed: D14.2 (A), SW14.2
unnamed: D15.2 (A), SW15.2
unnamed: D16.2 (A), SW16.2
unnamed: D17.2 (A), SW17.2
unnamed: D18.2 (A), SW18.2
unnamed: D19.2 (A), SW19.2
unnamed: D20.2 (A), SW20.2
unnamed: D21.2 (A), SW21.2
unnamed: D22.2 (A), SW22.2
unnamed: D23.2 (A), SW23.2
unnamed: D24.2 (A), SW24.2
unnamed: D25.2 (A), SW25.2
unnamed: D26.2 (A), SW26.2
unnamed: D27.2 (A), SW27.2
unnamed: D28.2 (A), SW28.2
unnamed: D29.2 (A), SW29.2
unnamed: D30.2 (A), SW30.2
unnamed: D31.2 (A), SW31.2
unnamed: D32.2 (A), SW32.2
unnamed: D33.2 (A), SW33.2
unnamed: D34.2 (A), SW34.2
unnamed: D35.2 (A), SW35.2
unnamed: D36.2 (A), SW36.2
unnamed: D37.2 (A), SW37.2
unnamed: D38.2 (A), SW38.2
unnamed: D39.2 (A), SW39.2
unnamed: D40.2 (A), SW40.2
unnamed: D41.2 (A), SW41.2
unnamed: D42.2 (A), SW42.2
unnamed: D43.2 (A), SW43.2
unnamed: D44.2 (A), SW44.2
unnamed: D45.2 (A), SW45.2
unnamed: D46.2 (A), SW46.2
unnamed: D47.2 (A), SW47.2
unnamed: D48.2 (A), SW48.2
unnamed: D49.2 (A), SW49.2
unnamed: D50.2 (A), SW50.2
unnamed: D51.2 (A), SW51.2
unnamed: D52.2 (A), SW52.2
unnamed: D53.2 (A), SW53.2
unnamed: D54.2 (A), SW54.2
unnamed: D55.2 (A), SW55.2
unnamed: D56.2 (A), SW56.2
unnamed: D57.2 (A), SW57.2
unnamed: D58.2 (A), SW58.2
unnamed: D59.2 (A), SW59.2
unnamed: D60.2 (A), SW60.2
unnamed: D61.2 (A), SW61.2
unnamed: D62.2 (A), SW62.2
unnamed: D63.2 (A), SW63.2
unnamed: D64.2 (A), SW64.2
unnamed: D65.2 (A), SW65.2
unnamed: D66.2 (A), SW66.2
unnamed: D67.2 (A), SW67.2
unnamed: D68.2 (A), SW68.2
unnamed: D69.2 (A), SW69.2
unnamed: D70.2 (A), SW70.2
unnamed: D71.2 (A), SW71.2
unnamed: D72.2 (A), SW72.2
unnamed: D73.2 (A), SW73.2
unnamed: D74.2 (A), SW74.2
unnamed: D75.2 (A), SW75.2
unnamed: D76.2 (A), SW76.2
unnamed: D77.2 (A), SW77.2
unnamed: D78.2 (A), SW78.2
unnamed: D79.2 (A), SW79.2
unnamed: D80.2 (A), SW80.2
unnamed: D81.2 (A), SW81.2
unnamed: D82.2 (A), SW82.2
unnamed: D83.2 (A), SW83.2
unnamed: D84.2 (A), SW84.2
unnamed: D85.2 (A), SW85.2
unnamed: D86.2 (A), SW86.2
unnamed: D87.2 (A), SW87.2
unnamed: D88.2 (A), SW88.2
unnamed: D89.2 (A), SW89.2
unnamed: D90.2 (A), SW90.2
unnamed: D91.2 (A), SW91.2
unnamed: D92.2 (A), SW92.2
unnamed: D93.2 (A), SW93.2
unnamed: D94.2 (A), SW94.2
unnamed: D95.2 (A), SW95.2
unnamed: D96.2 (A), SW96.2
unnamed: D97.2 (A), SW97.2
unnamed: D98.2 (A), SW98.2
unnamed: D99.2 (A), SW99.2
unnamed: F1.1, Q1.3 (D), U3.3 (-)
unnamed: FB1.1, J1.S1 (SHIELD)
unnamed: J1.A5 (CC1), R1.2
unnamed: J1.B5 (CC2), R2.2
unnamed: Q1.1 (G), U3.4
unnamed: RGB1.2 (DOUT), RGB14.4 (DIN)
unnamed: RGB1.4 (DIN), RGB2.2 (DOUT)
unnamed: RGB2.4 (DIN), RGB3.2 (DOUT)
unnamed: RGB3.4 (DIN), RGB4.2 (DOUT)
unnamed: RGB4.4 (DIN), RGB5.2 (DOUT)
unnamed: RGB5.4 (DIN), RGB6.2 (DOUT)
unnamed: RGB6.4 (DIN), RGB7.2 (DOUT)
unnamed: RGB7.4 (DIN), RGB8.2 (DOUT)
unnamed: RGB8.4 (DIN), RGB9.2 (DOUT)
unnamed: RGB9.4 (DIN), RGB10.2 (DOUT)
unnamed: RGB10.4 (DIN), RGB11.2 (DOUT)
unnamed: RGB11.4 (DIN), RGB12.2 (DOUT)
unnamed: RGB12.4 (DIN), RGB13.2 (DOUT)
unnamed: RGB14.2 (DOUT), RGB15.4 (DIN)
unnamed: RGB15.2 (DOUT), RGB16.4 (DIN)
unnamed: RGB16.2 (DOUT), RGB17.4 (DIN)
unnamed: RGB17.2 (DOUT), RGB18.4 (DIN)
unnamed: RGB18.2 (DOUT), RGB19.4 (DIN)
unnamed: RGB19.2 (DOUT), RGB20.4 (DIN)
unnamed: RGB20.2 (DOUT), RGB21.4 (DIN)
unnamed: RGB21.2 (DOUT), RGB22.4 (DIN)
unnamed: RGB22.2 (DOUT), RGB23.4 (DIN)
unnamed: RGB23.2 (DOUT), RGB24.4 (DIN)
unnamed: RGB24.2 (DOUT), RGB25.4 (DIN)
unnamed: RGB25.2 (DOUT), RGB26.4 (DIN)
unnamed: RGB26.2 (DOUT), RGB27.4 (DIN)
unnamed: RGB27.2 (DOUT), RGB28.4 (DIN)
unnamed: RGB28.2 (DOUT), RGB29.4 (DIN)
unnamed: RGB29.2 (DOUT), RGB30.4 (DIN)
unnamed: RGB30.2 (DOUT), RGB31.4 (DIN)
unnamed: RGB31.2 (DOUT), RGB32.4 (DIN)
unnamed: RGB32.2 (DOUT), RGB51.4 (DIN)
unnamed: RGB33.2 (DOUT), RGB52.4 (DIN)
unnamed: RGB33.4 (DIN), RGB34.2 (DOUT)
unnamed: RGB34.4 (DIN), RGB35.2 (DOUT)
unnamed: RGB35.4 (DIN), RGB36.2 (DOUT)
unnamed: RGB36.4 (DIN), RGB37.2 (DOUT)
unnamed: RGB37.4 (DIN), RGB38.2 (DOUT)
unnamed: RGB38.4 (DIN), RGB39.2 (DOUT)
unnamed: RGB39.4 (DIN), RGB40.2 (DOUT)
unnamed: RGB40.4 (DIN), RGB41.2 (DOUT)
unnamed: RGB41.4 (DIN), RGB42.2 (DOUT)
unnamed: RGB42.4 (DIN), RGB43.2 (DOUT)
unnamed: RGB43.4 (DIN), RGB44.2 (DOUT)
unnamed: RGB44.4 (DIN), RGB45.2 (DOUT)
unnamed: RGB45.4 (DIN), RGB46.2 (DOUT)
unnamed: RGB46.4 (DIN), RGB47.2 (DOUT)
unnamed: RGB47.4 (DIN), RGB48.2 (DOUT)
unnamed: RGB48.4 (DIN), RGB49.2 (DOUT)
unnamed: RGB49.4 (DIN), RGB50.2 (DOUT)
unnamed: RGB50.4 (DIN), RGB51.2 (DOUT)
unnamed: RGB52.2 (DOUT), RGB53.4 (DIN)
unnamed: RGB53.2 (DOUT), RGB54.4 (DIN)
unnamed: RGB54.2 (DOUT), RGB55.4 (DIN)
unnamed: RGB55.2 (DOUT), RGB56.4 (DIN)
unnamed: RGB56.2 (DOUT), RGB57.4 (DIN)
unnamed: RGB57.2 (DOUT), RGB58.4 (DIN)
unnamed: RGB58.2 (DOUT), RGB59.4 (DIN)
unnamed: RGB59.2 (DOUT), RGB60.4 (DIN)
unnamed: RGB60.2 (DOUT), RGB61.4 (DIN)
unnamed: RGB61.2 (DOUT), RGB62.4 (DIN)
unnamed: RGB62.2 (DOUT), RGB63.4 (DIN)
unnamed: RGB63.2 (DOUT), RGB64.4 (DIN)
unnamed: RGB64.2 (DOUT), RGB65.4 (DIN)
unnamed: RGB65.2 (DOUT), RGB66.4 (DIN)
unnamed: RGB66.2 (DOUT), RGB67.4 (DIN)
unnamed: RGB67.2 (DOUT), RGB68.4 (DIN)
unnamed: RGB68.2 (DOUT), RGB86.4 (DIN)
unnamed: RGB69.2 (DOUT), RGB87.4 (DIN)
unnamed: RGB69.4 (DIN), RGB70.2 (DOUT)
unnamed: RGB70.4 (DIN), RGB71.2 (DOUT)
unnamed: RGB71.4 (DIN), RGB72.2 (DOUT)
unnamed: RGB72.4 (DIN), RGB73.2 (DOUT)
unnamed: RGB73.4 (DIN), RGB74.2 (DOUT)
unnamed: RGB74.4 (DIN), RGB75.2 (DOUT)
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

Board: 2 copper layers, 420 parts (199 on the bottom side), 256 nets, no tracks yet.

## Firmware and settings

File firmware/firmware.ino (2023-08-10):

#include "config.h"
#include "backlight.h"
#include "keyboard.h"
#include "constants.h"
#include <stdint.h>
#include <FastLED.h>

#include "teensy4ledcontroller.h"

const int DELAY_MICROS = 16000;

Ze::Board keyboard;
Backlight backlight;

CRGB leds[NUM_LEDS];

#ifdef V3
byte pinList[1] = { 38 };
DMAMEM int displayMemory[NUM_LEDS * 3 / 4];
int drawingMemory[NUM_LEDS * 3 / 4];
OctoWS2811 octo(NUM_LEDS, displayMemory, drawingMemory, WS2811_RGB | WS2811_800kHz, 1, pinList);
CTeensy4Controller<GRB, WS2811_800kHz>* pcontroller;
#endif

uint8_t count;

void smart_delay(unsigned long start_time);

void check_serial();

void setup() {

#ifdef V2
    FastLED.addLeds<NEOPIXEL, 3>(leds, NUM_LEDS);
#elif defined V3
    octo.begin();
    pcontroller = new CTeensy4Controller<GRB, WS2811_800kHz>(&octo);
    FastLED.setBrightness(255);
    FastLED.addLeds(pcontroller, leds, NUM_LEDS);
#else
    FastLED.addLeds<NEOPIXEL, 2>(leds, NUM_LEDS);
#endif

    FastLED.clear();

#ifdef FULLSIZE
    FastLED.setMaxPowerInVoltsAndMilliamps(5, 800);
#elif defined V2 
    FastLED.setMaxPowerInVoltsAndMilliamps(5, 900);
#elif defined V3 
    FastLED.setMaxPowerInVoltsAndMilliamps(5, 900);
#else
    FastLED.setMaxPowerInVoltsAndMilliamps(5, 500);
#endif


    delay(50);

    FastLED.show();
    keyboard.init();

    backlight.init(&keyboard, leds);

    backlight.setup(BacklightStyle::STANDARD);
    Serial.begin(9600);

    delay(500);

}


void loop() {

    unsigned long start_time = micros();

    keyboard.update();
     
    backlight.update();

    smart_delay(start_time);

}

void smart_delay(unsigned long start_time) {
    unsigned long time = micros();

    // overflow has occurred
    if (time < start_time) return;

    unsigned long elapsed = time - start_time;
    if (elapsed > DELAY_MICROS) {
        // Serial.print("Computing took more than 16 ms: ");
        // Serial.println(elapsed);
        return;
    }
    delayMicroseconds(DELAY_MICROS - elapsed);
}

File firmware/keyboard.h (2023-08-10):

#ifndef KEYBOARD_H
#define KEYBOARD_H

#include <stdint.h>
#include <Arduino.h>
#include "constants.h"

namespace Ze {

    const int KEY_DUMMY = 0;

    // Codes for modifiers, but aren't actual
    // keycodes for the modifiers, but exist to
    // make things more efficient. Do not change
    // these.
    const int KEY_LSHIFT = -1;
    const int KEY_CTRL = -2;
    const int KEY_ALT = -3;
    const int KEY_ALTGR = -4;
    const int KEY_SUPER = -5;
    const int KEY_RSHIFT = -6;

    // Again, these keycodes are not sent, but used
    // to control behavior of other keys
    const int KEY_FN = -7;
    const int KEY_LOCK = -8;

#ifdef SIXTY_PERCENT 
    // Keycode for changing the backlight brightness
    const int KEY_INC_BRIGHTNESS = KEY_RSHIFT;

    // Keycode for changing the backlight style
    const int KEY_BACKLIGHT_STYLE = KEY_LSHIFT;
#else
    // Keycode for changing the backlight brightness
    const int KEY_INC_BRIGHTNESS = -100;

    // Keycode for changing the backlight style
    const int KEY_BACKLIGHT_STYLE = -101;
#endif

#ifdef V3
    const int KEY_EXTRA = -102;

    const int KEY_MACRO1 = -103;
    const int KEY_MACRO2 = -104;
    const int KEY_MACRO3 = -105;
    const int KEY_MACRO4 = -106;
    const int KEY_MACRO5 = -107;
#endif

    const uint8_t NUM_MODIFIERS = 6;

    const uint8_t READ_DELAY = 5;

    struct Key {

        /*
         * Initializes dummy key.
         */
        Key();

        /*
         * Initializes key without second function.
         */
        Key(int code, uint8_t row, uint8_t col);

        /*
         * Initializes key with main and second function.
         */
        Key(int main, int second, uint8_t row, uint8_t col);

        /*
         * Checks whether this key is a modifier key.
         */
        bool is_modifier() const;

        /*
         * Checks whether this key is a media key.
         */
        bool is_media() const;

        /*
         * Checks whether this key is a dummy key.
         */
        bool is_dummy() const;

        /*
         * Checks whether this key is the FN key.
         */
        bool is_fn() const;

        /*
         * Checks whether this key has a second function.
         */
        bool has_second() const;

        bool operator==(const Key& other) const;

        bool operator!=(const Key& other) const;

        /* 
         * The keycode for the main function of this key.
         */
        int code;

        /*
         * The keycode for the second function of this key,
         * that is, the function this key will have when 
         * the FN-key is pressed. If this key has no second
         * function, this is set as KEY_DUMMY.
         */
        int second;

        uint8_t row;

        uint8_t col;
    
    };

    class Board {

        public:
            
            /*
             * Initializes the keyboard, by initializing
             * the ports to the switches. Does not initialize
             * the backlighting.
             */
            void init();

            void update();

            Key* get_curr_pressed_keys();

            Key* get_just_released_keys();

            uint8_t get_num_keys_pressed();

            uint8_t get_num_released_keys();

            bool brightness_inc_pressed();

            bool backlight_style_changed();

            bool is_just_pressed[NUM_ROWS][NUM_COLS];

        private:

            bool been_pressed[NUM_ROWS][NUM_COLS];

            const int MODIFIER_MAP[NUM_MODIFIERS] = {

                MODIFIERKEY_LEFT_SHIFT,
                MODIFIERKEY_CTRL,
                MODIFIERKEY_LEFT_ALT,
                MODIFIERKEY_RIGHT_ALT,
                MODIFIERKEY_GUI,
                MODIFIERKEY_RIGHT_SHIFT

            };

#ifdef SIXTY_PERCENT
            const uint8_t ROW_PINS[NUM_ROWS] = {0, 4, 5, 6, 7};
            const uint8_t COL_PINS[NUM_COLS] = 
            {
                8, 9, 10, 11, 12, 14, 15, 16, 17, 18, 19, 20, 21, 22
            };
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

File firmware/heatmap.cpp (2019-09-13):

#include "heatmap.h"
#include "config.h"
#ifdef SIXTY_PERCENT
    #include "sixty_layout.h"
#elif defined FULLSIZE
    #include "fullsize_layout.h"
#elif defined V2
    #include "v2_layout.h"
#endif
#include "util.h"
#include <Arduino.h>

bool get_position_of_pressed_key(Position* p, Ze::Board* board) {
    for (uint8_t row = 0; row < Ze::NUM_ROWS; ++row) {
        for (uint8_t col = 0; col < Ze::NUM_COLS; ++col) {
            if (board->is_just_pressed[row][col]) {
                p->row = row;
                p->col = col;
                return true;
            }
        }
    }
    return false;
}

void heatmap_setup(LED leds[][Ze::NUM_COLS],
        Position* previously_pressed,
        uint32_t count_map[][Ze::NUM_COLS][Ze::NUM_ROWS][Ze::NUM_COLS]) {
    for (uint8_t row = 0; row < Ze::NUM_ROWS; ++row) {
        for (uint8_t col = 0; col < Ze::NUM_COLS; ++col) {
            leds[row][col].r = 0;
            leds[row][col].g = 0;
            leds[row][col].b = 0;
        }
    }
}

void heatmap_update(LED leds[][Ze::NUM_COLS],
        uint32_t count_map[][Ze::NUM_COLS][Ze::NUM_ROWS][Ze::NUM_COLS],
        Position* previously_pressed,
        Ze::Board* board, uint64_t it) {
    Position p;
    bool pressed = get_position_of_pressed_key(&p, board);
    if (!pressed) return;

    uint8_t pr = previously_pressed->row;
    uint8_t pc = previously_pressed->col;

    uint8_t r = p.row;
    uint8_t c = p.col;

    count_map[pr][pc][r][c]++;

    previously_pressed->row = r;
    previously_pressed->col = c;

    uint32_t max = 0;
    for (uint8_t row = 0; row < Ze::NUM_ROWS; ++row) {
        for (uint8_t col = 0; col < Ze::NUM_COLS; ++col) {
            if (count_map[r][c][row][col] > max) {
                max = count_map[r][c][row][col];
                Serial.println(count_map[r][c][row][col]);
            }
        }
    }

    for (uint8_t row = 0; row < Ze::NUM_ROWS; ++row) {
        for (uint8_t col = 0; col < Ze::NUM_COLS; ++col) {
            uint8_t intensity;
            float count = (float)count_map[r][c][row][col];
            if (max == 0) {
                intensity = 0;
            } else {
                float intensity_f = (count/((float)max))*255.0;
                intensity = ((uint8_t)intensity_f);
                Serial.print(count);
                Serial.print(", ");
                Serial.print(intensity_f);
                Serial.print(", ");
                Serial.print(intensity);
                Serial.print(", ");
                Serial.println(max);
            }
            if (intensity == 0) {
                leds[row][col].r = 0;
                leds[row][col].g = 0;
                leds[row][col].b = 0;
            } else {
                Color c;
                jet_color_map(intensity, c);

                leds[row][col].r = c.r;
                leds[row][col].g = c.g;
                leds[row][col].b = c.b;
            }
        }
    }
}

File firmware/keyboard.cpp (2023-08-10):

#include <Keyboard.h>
#include "config.h"

#ifdef SIXTY_PERCENT
    #include "sixty_layout.h"
#elif defined FULLSIZE
    #include "fullsize_layout.h"
#elif defined V2
    #include "v2_layout.h"
#elif defined V3
    #include "v3_layout.h"
#endif
#include "keyboard.h"


Ze::Key::Key() {
    this->code = KEY_DUMMY;
}

Ze::Key::Key(int code, uint8_t row, uint8_t col) {
    this->code = code;
    this->row = row;
    this->col = col;
    this->second = KEY_DUMMY;
}

Ze::Key::Key(int code, int second, uint8_t row, uint8_t col) {
    this->code = code;
    this->row = row;
    this->col = col;
    this->second = second;
}

bool Ze::Key::is_modifier() const {
    return this->code < 0;
}

bool Ze::Key::is_media() const {
    return (0xFF00 & this->code) == 0xE400;
}

bool Ze::Key::is_dummy() const {
    return code == KEY_DUMMY;
}

bool Ze::Key::operator==(const Key& other) const {
    return code == other.code && second == other.second;
}

bool Ze::Key::operator!=(const Key& other) const {
    return !(*this == other);
}

bool Ze::Key::is_fn() const {
    return code == KEY_FN;
}

bool Ze::Key::has_second() const {
    return second != KEY_DUMMY;
}

int Ze::Board::translate_modifier(const int modifier) const {
    if (modifier >= 0) return -1;
    return MODIFIER_MAP[-1 * modifier - 1];
}

bool Ze::Board::brightness_inc_pressed() {
#ifdef FULLSIZE
    return this->b_inc_pressed;
#else 
    return this->b_inc_pressed && this->fn_pressed;
#endif
}

bool Ze::Board::backlight_style_changed() {
#ifndef SIXTY_PERCENT 
    return this->b_style_pressed;
#else
    return this->b_style_pressed && this->fn_pressed;
#endif
}

void Ze::Board::init() {

    // Set the rows as outputs
    for (uint8_t r = 0; r < NUM_ROWS; ++r) {
        pinMode(ROW_PINS[r], OUTPUT);
        digitalWrite(ROW_PINS[r], HIGH);
    }

    // Set the columns as inputs with pull up resistors
    for (uint8_t c = 0; c < NUM_COLS; ++c) {
        pinMode(COL_PINS[c], INPUT_PULLUP);
    }

    fn_pressed = false;
    num_keys_pressed = 0;
    tot_num_keys_pressed = 0;
    current_media = 0;

    // Initialize the key buffers to nullptrs
    for (uint8_t i = 0; i < MAX_NUM_KEYS; ++i) {
        curr_pressed_keys[i] = Key();
        keys_to_send[i] = Key();
        codes_to_send[i] = 0;
    }

    // Initialize the all_pressed_keys array.
    for (uint8_t i = 0; i < NUM_ROWS * NUM_COLS; ++i) {
        all_pressed_keys[i] = Key();
    }

    for (uint8_t row = 0; row < NUM_ROWS; ++row) {
        for (uint8_t col = 0; col < NUM_COLS; ++col) {
            is_just_pressed[row][col] = false;
            been_pressed[row][col] = false;
        }
    }
}

void Ze::Board::reset_pressed_keys() {
    for (uint8_t i = 0; i < MAX_NUM_KEYS; ++i) {
        curr_pressed_keys[i] = Key();
        just_released_keys[i] = Key();
    }

    for (uint8_t i = 0; i < NUM_ROWS * NUM_COLS; ++i) {
        if (all_pressed_keys[i].is_dummy()) break;
        all_pressed_keys[i] = Key();
    }
}

Ze::Key* Ze::Board::get_curr_pressed_keys() {
    return this->all_pressed_keys;
}

Ze::Key* Ze::Board::get_just_released_keys() {
    return this->just_released_keys;
}

uint8_t Ze::Board::get_num_keys_pressed() {
    return this->tot_num_keys_pressed;
}

uint8_t Ze::Board::get_num_released_keys() {
    return this->num_keys_released;
}

void Ze::Board::update() {
    reset_pressed_keys();
    num_keys_pressed = 0;
    num_keys_released = 0;
    tot_num_keys_pressed = 0;
    current_modifier = 0;
    b_inc_pressed = false;
    b_style_pressed = false;
    pressed_media = Key();
    fn_pressed = false;

    scan_keys();
    
    update_keys_to_send();
    send_keys();
    
}

void Ze::Board::scan_keys() {

    for (uint8_t row = 0; row < NUM_ROWS; ++row) {

        // set this row to low
        digitalWrite(ROW_PINS[row], LOW);
        delayMicroseconds(READ_DELAY);

        for (uint8_t col = 0; col < NUM_COLS; ++col) {
            if (!KEYS[row][col].is_dummy()) {
                
                if (digitalRead(COL_PINS[col]) == LOW) {
                    // non dummy key is pressed

                    is_just_pressed[row][col] = !been_pressed[row][col];
                    been_pressed[row][col] = true;
                    
                    Key pressed = KEYS[row][col];
                    all_pressed_keys[tot_num_keys_pressed] = pressed;
                    tot_num_keys_pressed++;

                    if (pressed.is_fn()) {

                        this->fn_pressed = true;

                    } 
#ifdef FULLSIZE
                    else if (pressed.code == KEY_INC_BRIGHTNESS) {
                        b_inc_pressed = true;
                    }
#endif
#ifndef SIXTY_PERCENT 
                    else if (pressed.code == KEY_BACKLIGHT_STYLE) {
                        b_style_pressed = true;
                    }
#endif
                    else if (pressed.is_modifier()) {

                        current_modifier |= translate_modifier(pressed.code);
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

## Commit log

2016-10-10 Added design folder and files
    [keyboard.scad, layout.scad]
2016-10-10 Added the stl parts and created a blender project
    [keyboard.blend, part1.stl, part2.stl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]
2016-10-10 Merged some faces
    [keyboard.blend]
2016-10-11 Dissolved some faces and added gitignore
    [keyboard.blend]
2016-10-11 Added bottom plate and edges to switch plate
    [keyboard.blend]
2016-10-12 Minor changes
    [keyboard.blend]
2016-10-12 Started making more space for space bar stabilizers
    [keyboard.blend]
2016-10-13 Can't really edit the plate more until I get the stabilizers, also realized the bottom plate needs redesign
    [keyboard.blend]
2016-10-14 Fixed bottom plate and added frame to top plate
    [keyboard.blend]
2016-10-14 Made room for stabilizers
    [keyboard.blend]
2016-10-16 Made keyboard thicker, added room for stabilizers and removed duplicate faces
    [keyboard.blend]
2016-10-17 Started adding screwholes
    [keyboard.blend]
2016-10-18 Tested exporting stl
    [test.stl]
2016-10-18 Tried exporting stl through openscad
    [anothertest.stl]
2016-10-18 Deleted test files
    [anothertest.stl, test.stl]
2016-10-18 Added all screwholes on both the frame and the bottom plate
    [keyboard.blend]
2016-10-25 Fixed hanging screw holes and finished bottom plate
    [keyboard.blend]
2016-10-26 Added platform for usb and adjusted screwholes
    [keyboard.blend]
2016-10-26 Added rounded edges
    [keyboard.blend]
2016-10-26 Finished model
    [keyboard.blend]
2016-10-26 Angled bottom instead
    [keyboard.blend]
2016-10-31 Started writing firmware
    [keyboard.scad, part1.stl, part2.stl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]
2016-10-31 Removed scad layout
    [layout.scad]
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2016-11-02 Fixed incorrect led constant
    [keyboard.h]
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2016-11-25 The shit doesn't compile
    [backlight.cpp, constants.h, firmware.ino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]
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2017-01-15 Fixed water color problem and improved brightness adjustment
    [backlight.cpp, water.h]
2017-01-19 Fixed problem when switching from water to standard
2017-02-04 Added keyboard stl
    [keyboard.stl]
2017-02-04 Fixed stl
    [keyboard.stl]
2017-12-02 Tetrominos now spawn, fall and collision detect
    [tetrisboard.cpp]
2017-12-06 Finally solved the freezing issue
    [tetrisboard.cpp]
2018-01-14 Started working on layout script
    [fullsize.blend]
2018-01-15 Completed switch holes
    [fullsize.blend]
2018-01-16 Added stabilizer holes
    [fullsize.blend]
2018-01-17 Added faces on the bottom
    [fullsize.blend]
2018-01-21 Added some more stuff
    [fullsize.blend]
2018-01-22 Completed top side of plate
    [fullsize.blend]
2018-01-23 Minor things
    [fullsize.blend]
2018-02-03 Finished plate and started separating them
    [fullsize.blend]
2018-02-03 Separated another part
    [fullsize.blend]
2018-02-04 All parts are now separated and started working on case
    [fullsize.blend]
2018-02-05 Scaled everything by 0.99 and continued modeling case
    [fullsize.blend]
2018-02-06 Did som segmenting of case
    [fullsize.blend]
2018-02-07 Added a hole for the nuts
    [fullsize.blend]
2018-02-09 Forgot to save
    [fullsize.blend]
2018-02-11 Replaced nut holes with screw holes
    [fullsize.blend]
2018-02-27 Finished a screw hole
    [fullsize.blend]
2018-03-18 Added screwholes between arrow keys and numpad
    [fullsize.blend]
2018-03-19 Added even more screwholes
    [fullsize.blend]
2018-04-05 Added eeeeven mooore screw holes again
    [fullsize.blend]
2018-04-06 Done with screwholes in the plate
    [fullsize.blend]
2018-05-05 Finished screw holes on the back side of the case
    [fullsize.blend]
2018-05-09 Finished screw holes in case for the plate
    [fullsize.blend]
2018-06-04 Chamfered bottom of case, added screw holes for support
    [fullsize.blend]
2018-06-13 Finish bottom plate and fix incorrect space bar stabilizer size
    [fullsize.blend]
2018-06-23 Add support
    [fullsize.blend]
2018-07-07 Everything is ready for printing
    [fullsize.blend]
2018-10-30 All the hardware now works
    [fullsize.blend]
2019-06-28 Add new layout
    [v2.blend]
2019-06-28 Start removing bottom row
    [v2.blend]
2019-07-02 Finish removing top row from plate
    [v2.blend]
2019-07-04 Add logo and finish layout
    [v2.blend]
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2019-07-11 A lot of progress on the handrest
    [v2.blend]
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2019-07-17 Fix missing parts I think
    [v2.blend]
2019-07-17 Add some holes in cases
    [v2.blend]
2019-07-17 More changes to case, including joining plates
    [v2.blend]
2019-07-17 Create the keyboard angle
    [v2.blend]
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2019-08-01 Add USB connection hole, enlargened LED-compartment in handrest and other things
    [v2.blend]
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2019-08-11 Some code cleanup and add models
    [case_center_left.stl, case_center_right.stl, case_left.stl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]
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2019-08-18 Fix water effect on v2
    [water.h]
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2019-09-13 Remove resetting of heatmap
    [heatmap.cpp]
2021-11-20 Start on v3 keyboard
    [v3.blend]
2021-12-05 Start moving spacebar to it's own part
    [v3.blend]
2021-12-07 Joined all plates with the space bar
    [v3.blend]
2021-12-14 Join numpad with rest and add extra column
    [v3.blend]
2021-12-18 Prepared edge for case
    [v3.blend]
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2022-04-05 Move the extra column a little
    [v3.blend]
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2023-03-07 Add new layout for v3
    [v3.kicad_pcb, v3.kicad_sch]
2023-03-09 Replace switch footprints with hotswap sockets
    [v3.kicad_pcb, v3.kicad_sch]
2023-03-13 Add level shifter and everything else for the RGBs
    [v3.kicad_pcb, v3.kicad_sch]
2023-03-18 Align LED:s and add stabilizer holes
    [v3.kicad_pcb, v3.kicad_sch]
2023-03-18 Reorient LEDs and started on USB
    [v3.kicad_pcb, v3.kicad_sch]
2023-03-19 Finished USB and add pinouts for teensy
    [v3.kicad_pcb, v3.kicad_sch]
2023-03-22 Add logo LEDS, adjust zones, remove unnecessary components
    [v3.kicad_sch]
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2023-03-23 Add some part numbers and start adding row tracks
    [v3.kicad_sch]
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2023-03-27 PCB might be ready for manufacturing
    [v3.kicad_sch]
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2023-04-19 Fix the mistakes of the produced PCB
    [v3.kicad_sch]
2023-04-19 Designed the inner plate
    [even_better_inner_plate.FCStd, inner_plate.dxf]
2023-04-19 Started on outer plate
    [outer_plate.FCStd]
2023-04-25 Update PCB for layout-4
    [v3.kicad_sch]
2023-06-04 Ready for production 2
    [v3.kicad_sch]
2023-06-11 Start working on case
    [case.FCStd, v3-User_Eco2.dxf]
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2023-06-21 Set correct distance between plate and pcb
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2023-09-25 WIP: trying to fix the broken case
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2023-10-17 Fix some features with the case and add custom keycaps
    [keycap.FCStd]
